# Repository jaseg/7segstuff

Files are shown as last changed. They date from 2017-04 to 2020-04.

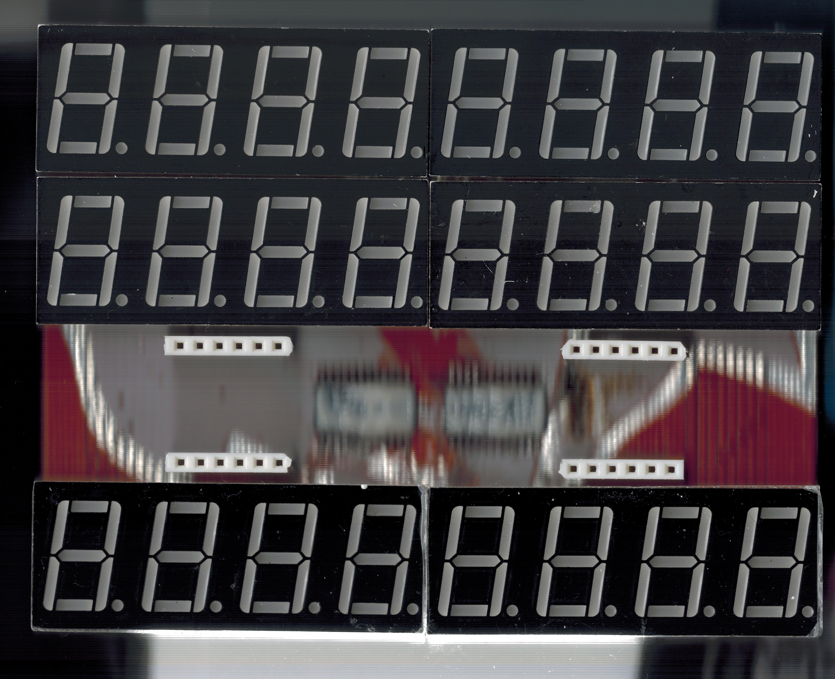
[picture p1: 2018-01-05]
fw/tools/scans/megumin_segmentmap_600dpi.jpg

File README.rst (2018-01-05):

Megumin LED display
===================

This repository contains schematics, firmware, host controller code and board
layouts for driving of hundreds of 7-segment displays. The firmware and some
basic host software may be found in the fw directory. The hardware design files
may be found in the hw directory.

This system uses a somewhat involved LED modulation technique. For details on
that have a look at the README.rst in the fw directory as well as the
well-documented code in fw/display.c.

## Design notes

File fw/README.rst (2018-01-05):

Note on the LED modulation 
==========================

To control LED brightness, this project uses a modulation technique known as
"Binary Code Modulation" (BCM) or "Bit Angle Modulation" (BAM). The base idea is
to clock out all outputs in parallel bit-by-bit, then modulate this with a
precisely timed output enable signal. In contrast to PWM this allows almost
arbitrarily high channel counts and configurable modulation resolution at low
CPU overhead and high frame rates. In this project that is needed due to the
large number of channels (32) and the medium oversampling rate (1:8).

A good article explaining BCM can be found on batsocks.co.uk_ and a nice video
explaining has been published by mikeselectricstuff_. A possible optimization
for even smoother brightness fading (probably mostly in unmultiplexed
applications) has been discussed in the forums at picbasic.co.uk_.

.. _mikeselectricstuff: https://www.youtube.com/watch?v=Sq8SxVDO5wE
.. _`picbasic.co.uk`: http://www.picbasic.co.uk/forum/showthread.php?t=7393
.. _batsocks.co.uk: http://www.batsocks.co.uk/readme/art_bcm_1.htm

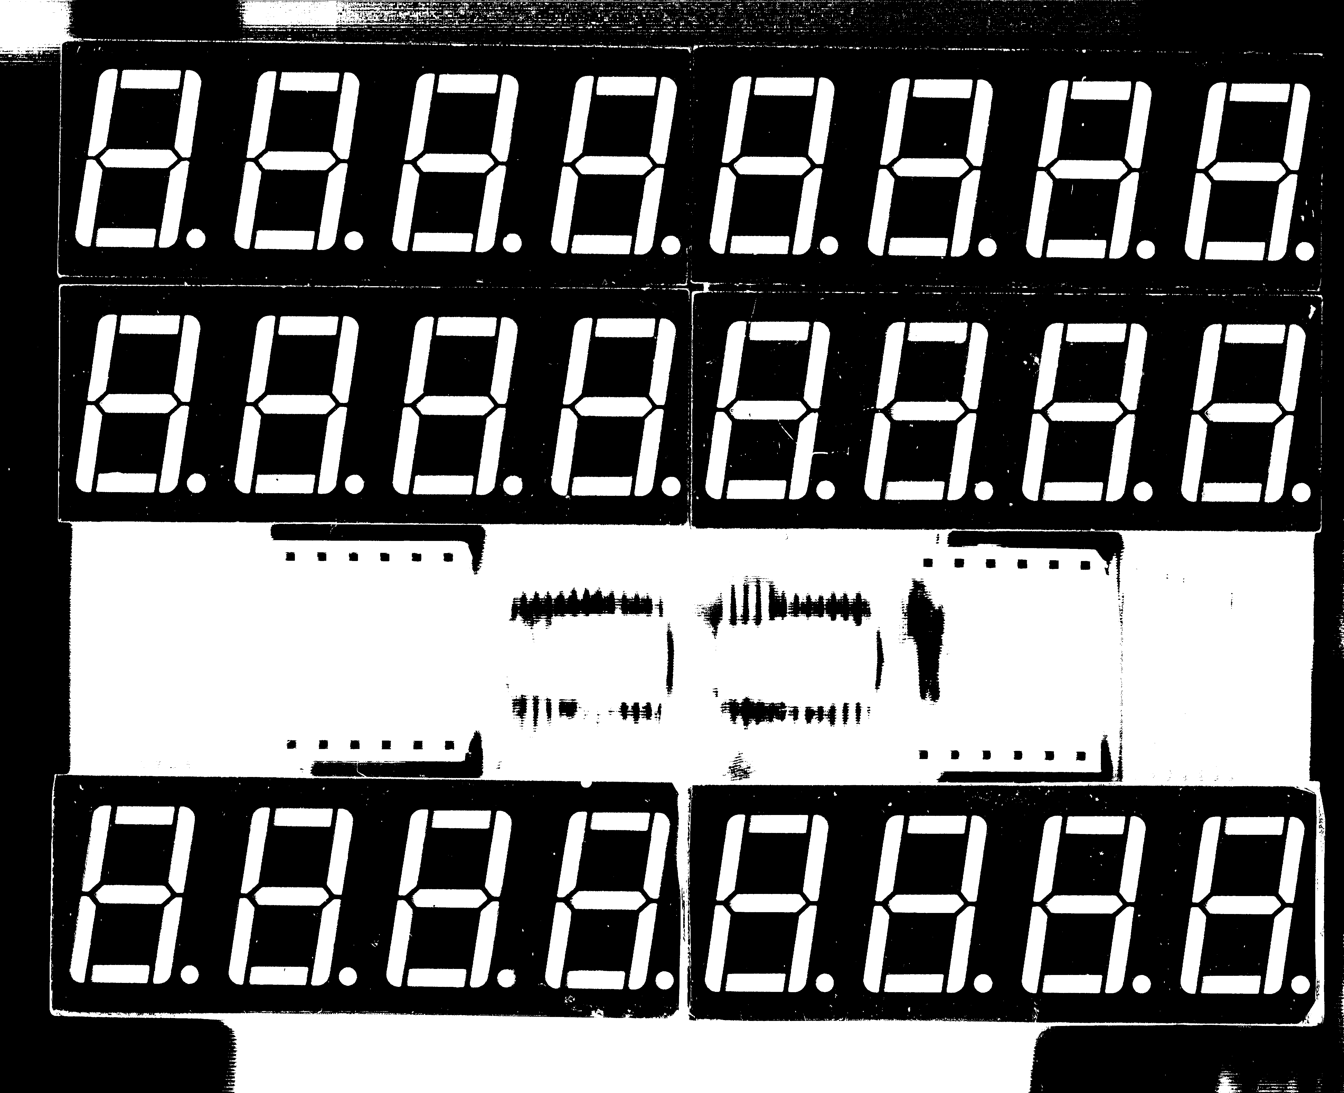
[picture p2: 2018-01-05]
fw/tools/scans/pretty2.png

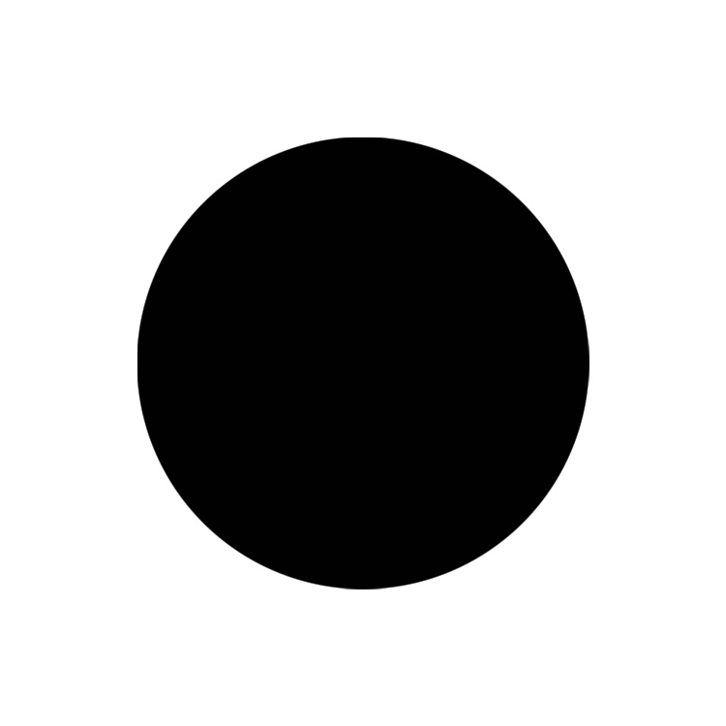
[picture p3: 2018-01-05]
fw/tools/circle.jpg

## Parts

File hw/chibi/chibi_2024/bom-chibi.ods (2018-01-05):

Chibi/Megumin
Number of devices: | Base: | 20
 | w/ cmeas: | 0
 | w/ watchdog: | 20
Description | Package | Mfg | Mfg Part No | Supplier | Reichelt PN | Qty watchdog | Qty cmeas | Qty base | MOQ | Unit | Price/ Unit | Price watchdog | Price cmeas | Price base | Price total | MOQ match | Price total MOQ | Excl | TempSum | MOQ delta cost | MOQ delta qty | URL
MLC X7R 100n | 0603 | Yageo | CC0603KRX7R7BB104 | Reichelt | X7R-G0603 100N | 1 | 1 | 8 | 10 | Pcs | 0.04 € | 0.04 € | 0.04 € | 0.32 € | 7.20 € | 180 | 7.20 € |  | 7.20 € | 0.00 € | 0 | https://www.reichelt.de/Vielschicht-SMD-G0603/X7R-G0603-100N/3/index.html?ACTION=3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
Electrolytic cap 1000u/10V | D10 L20 R5 | NCC | ELXZ160ETD102MJ20S | Reichelt | RAD LXZ 16/1K0 |  |  | 1 | 1 | Pcs | 0.24 € | 0.00 € | 0.00 € | 0.24 € | 4.80 € | 20 | 4.80 € |  | 4.80 € | 0.00 € | 0 | https://www.reichelt.de/Elkos-radial-105-C-5000-10000h/RAD-LXZ-16-1K0/3/index.html?ACTION=3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
Electrolytic cap 47u/6V | SMD 5x5.8 | Panasonic | EEEFK1C470UR | Reichelt | VF 47/16 K-C |  |  | 1 | 1 | Pcs | 0.12 € | 0.00 € | 0.00 € | 0.12 € | 2.40 € | 20 | 2.40 € |  | 2.40 € | 0.00 € | 0 | https://www.reichelt.de/Elkos-SMD-Low-ESR-105-C/VF-47-16-K-C/3/index.html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
MLC X7R 10n | 0603 | RND | RND1500603B224K100 | Reichelt | X7R-G0603 10N |  |  | 1 | 10 | Pcs | 0.04 € | 0.00 € | 0.00 € | 0.04 € | 0.80 € | 20 | 0.80 € |  | 0.80 € | 0.00 € | 0 | https://www.reichelt.de/Vielschicht-SMD-G0603/X7R-G0603-10N/3/index.html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
MLC X7R 220n | 0603 | Yageo | CC0603KRX7R9BB103 | Reichelt | X7R 0603 CC 220N |  | 2 |  | 10 | Pcs | 0.04 € | 0.00 € | 0.08 € | 0.00 € | 0.00 € | 0 | 0.00 € |  | 0.00 € | 0.00 € | 0 | https://www.reichelt.de/Vielschicht-SMD-G0603/X7R-0603-CC-220N/3/index.html?ACTION=3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
MLC NP0 22p | 0603 | Yageo | CC0603JRNPO9BN220 | Reichelt | NPO-G0603 22P |  |  | 2 | 10 | Pcs | 0.04 € | 0.00 € | 0.00 € | 0.08 € | 1.60 € | 40 | 1.60 € |  | 1.60 € | 0.00 € | 0 | https://www.reichelt.de/Vielschicht-SMD-G0603/NPO-G0603-22P/3/index.html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
Zener 6.4V 1.3W | THT | Generic |  | Reichelt | ZD 6,8 |  |  | 1 | 1 | Pcs | 0.06 € | 0.00 € | 0.00 € | 0.06 € | 1.20 € | 20 | 1.20 € |  | 1.20 € | 0.00 € | 0 | https://www.reichelt.de/Z-Dioden-1-3W/ZD-6-8/3/index.html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
LED red | 0603 | Everlight | 19-213/R6C-AQ1R2B/3T | Reichelt | LED EL 0603 RT |  |  | 1 | 10 | Pcs | 0.08 € | 0.00 € | 0.00 € | 0.08 € | 1.60 € | 20 | 1.60 € |  | 1.60 € | 0.00 € | 0 | https://www.reichelt.de/SMD-LEDs-Standard/LED-EL-0603-RT/3/index.html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
LED yellow | 0603 | Everlight | 19-213/Y2C-CQ2R2L/3T | Reichelt | LED EL 0603 GE |  |  | 1 | 10 | Pcs | 0.06 € | 0.00 € | 0.00 € | 0.06 € | 1.20 € | 20 | 1.20 € |  | 1.20 € | 0.00 € | 0 | https://www.reichelt.de/SMD-LEDs-Standard/LED-EL-0603-GE/3/index.html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
LED green | 0603 | Everlight | LED EL 0603 GR1 | Reichelt | LED EL 0603 GR1 |  |  | 1 | 10 | Pcs | 0.10 € | 0.00 € | 0.00 € | 0.10 € | 2.00 € | 20 | 2.00 € |  | 2.00 € | 0.00 € | 0 | https://www.reichelt.de/SMD-LEDs-Standard/LED-EL-0603-GR1/3/index.html?ACTION=3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
Glass Fuse 5x20mm MT 2.5A | other | Generic |  | Reichelt | MTR. 2,5A |  |  | 1 | 10 | Pcs | 0.08 € | 0.00 € | 0.00 € | 0.08 € | 1.58 € | 20 | 1.58 € |  | 1.58 € | 0.00 € | 0 | https://www.reichelt.de/?ACTION=3;ARTICLE=13246;SEARCH=MT%202,5A
Fuse holder 5x20mm (single) | other | Generic |  | Reichelt | PL 120000 |  |  | 2 | 1 | Pcs | 0.06 € | 0.00 € | 0.00 € | 0.12 € | 2.40 € | 40 | 2.40 € |  | 2.40 € | 0.00 € | 0 | https://www.reichelt.de/Sicherungshalter/PL-120000/3/index.html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
Spade connector 6.35mm | THT | Generic |  | Reichelt | FS-P 6,35 |  |  | 0 | 10 | Pcs | 0.05 € | 0.00 € | 0.00 € | 0.00 € | 0.00 € | 0 | 0.00 € |  | 0.00 € | 0.00 € | 0 | https://www.reichelt.de/Flachstecker/FS-P-6-35/3/index.html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
Female header 1x4 100mil | other | Generic |  | Reichelt | SL 1X36G 2,54 |  |  | 1 | 9 | Pcs | 0.02 € | 0.00 € | 0.00 € | 0.02 € | 0.38 € | 27 | 0.51 € |  | 0.51 € | 0.13 € | 7 | https://www.reichelt.de/Stiftleisten/SL-1X36G-2-54/3/index.html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
Shrouded male header 2x5 100mil | other | Generic |  | Reichelt | WSL 10G |  |  | 1 | 1 | Pcs | 0.09 € | 0.00 € | 0.00 € | 0.09 € | 1.80 € | 20 | 1.80 € |  | 1.80 € | 0.00 € | 0 | https://www.reichelt.de/Pfosten-Wannenstecker/WSL-10G/3/index.html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
PNP signal transistor | SOT-23 | Generic |  | Reichelt | BC 857C SMD | 1 |  |  | 10 | Pcs | 0.04 € | 0.04 € | 0.00 € | 0.00 € | 0.80 € | 20 | 0.80 € |  | 0.80 € | 0.00 € | 0 | https://www.reichelt.de/BC-Transistoren/BC-857C-SMD/3/index.html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
NPN signal transistor | SOT-23 | Generic |  | Reichelt | BC 847C SMD |  |  | 2 | 10 | Pcs | 0.04 € | 0.00 € | 0.00 € | 0.08 € | 1.60 € | 40 | 1.60 € |  | 1.60 € | 0.00 € | 0 | https://www.reichelt.de/BC-Transistoren/BC-847C-SMD/3/index.html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
Metal film resistor 10k 1% | 0603 | Yageo | RC0603FR-0710KL | Reichelt | SMD-0603 10K | 2 | 4 | 2 | 10 | Pcs | 0.02 € | 0.03 € | 0.06 € | 0.03 € | 1.20 € | 80 | 1.20 € |  | 1.20 € | 0.00 € | 0 | https://www.reichelt.de/SMD-0603-von-1-bis-910-kOhm/SMD-0603-10K/3/index.html?ACTION=3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
Metal film resistor 47k 1% | 0603 | Yageo | RC0603FR-0747KL | Reichelt | SMD-0603 47K | 3 | 4 |  | 10 | Pcs | 0.02 € | 0.05 € | 0.06 € | 0.00 € | 0.90 € | 60 | 0.90 € |  | 0.90 € | 0.00 € | 0 | https://www.reichelt.de/SMD-0603-von-1-bis-910-kOhm/SMD-0603-47K/3/index.html?ACTION=3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
Metal film resistor 100k 1% | 0603 | Yageo | RC0603FR-07100KL | Reichelt | SMD-0603 100K | 2 |  | 4 | 10 | Pcs | 0.02 € | 0.03 € | 0.00 € | 0.06 € | 1.80 € | 120 | 1.80 € |  | 1.80 € | 0.00 € | 0 | https://www.reichelt.de/SMD-0603-von-1-bis-910-kOhm/SMD-0603-100K/3/index.html?ACTION=3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
Metal film resistor 4k7 1% | 0603 | Yageo | RC0603FR-074K7L | Reichelt | SMD-0603 4,7K |  | 3 | 2 | 10 | Pcs | 0.02 € | 0.00 € | 0.05 € | 0.03 € | 0.60 € | 40 | 0.60 € |  | 0.60 € | 0.00 € | 0 | https://www.reichelt.de/SMD-0603-von-1-bis-910-kOhm/SMD-0603-4-7K/3/index.html?ACTION=3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
Metal film resistor 1k 1% | 0603 | Yageo | RC0603FR-071KL | Reichelt | SMD-0603 1,0K |  | 1 |  | 10 | Pcs | 0.02 € | 0.00 € | 0.02 € | 0.00 € | 0.00 € | 0 | 0.00 € |  | 0.00 € | 0.00 € | 0 | https://www.reichelt.de/SMD-0603-von-1-bis-910-kOhm/SMD-0603-1-0K/3/index.html?ACTION=3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
Metal film resistor 470k 1% | 0603 | Yageo | RC0603FR-07470KL | Reichelt | SMD-0603 470K |  |  | 2 | 10 | Pcs | 0.02 € | 0.00 € | 0.00 € | 0.03 € | 0.60 € | 40 | 0.60 € |  | 0.60 € | 0.00 € | 0 | https://www.reichelt.de/SMD-0603-von-1-bis-910-kOhm/SMD-0603-470K/3/index.html?ACTION=3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
Metal film resistor 100 1% | 0603 | Yageo | RC0603FR-07100RL | Reichelt | SMD-0603 100 |  |  | 2 | 10 | Pcs | 0.02 € | 0.00 € | 0.00 € | 0.03 € | 0.60 € | 40 | 0.60 € |  | 0.60 € | 0.00 € | 0 | https://www.reichelt.de/SMD-0603-von-0-bis-910-Ohm/SMD-0603-100/3/index.html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
Metal film resistor 140 1% | 0603 | Yageo | RC0603FR-07150RL | Reichelt | SMD-0603 150 |  |  | 1 | 10 | Pcs | 0.02 € | 0.00 € | 0.00 € | 0.02 € | 0.30 € | 20 | 0.30 € |  | 0.30 € | 0.00 € | 0 | https://www.reichelt.de/SMD-0603-von-0-bis-910-Ohm/SMD-0603-150/3/index.html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
DAC resistor 1 | 0603 | Yageo |  | Reichelt |  |  |  | 2 | 10 | Pcs | 0.02 € | 0.00 € | 0.00 € | 0.03 € | 0.60 € | 40 | 0.60 € |  | 0.60 € | 0.00 € | 0
DAC resistor 2 | 0603 | Yageo |  | Reichelt |  |  |  | 2 | 10 | Pcs | 0.02 € | 0.00 € | 0.00 € | 0.03 € | 0.60 € | 40 | 0.60 € |  | 0.60 € | 0.00 € | 0
Linear voltage reg 3.3V | SOT-223 | Generic | LD1117-3.3 | Reichelt | TS 1117 BCW33 |  |  | 0 | 1 | Pcs | 0.32 € | 0.00 € | 0.00 € | 0.00 € | 0.00 € | 0 | 0.00 € |  | 0.00 € | 0.00 € | 0 | https://www.reichelt.de/ICs-TLC-TSA-/TS-1117-BCW33/3/index.html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
Generic dual op-amp | SO-8 | Generic | LM358 | Reichelt | LM 358 SMD |  | 1 |  | 1 | Pcs | 0.15 € | 0.00 € | 0.15 € | 0.00 € | 0.00 € | 0 | 0.00 € |  | 0.00 € | 0.00 € | 0 | https://www.reichelt.de/ICs-LM-10-LM-999/LM-358-SMD/3/index.html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
Generic dual comparator | SO-8 | Generic | LM393 | Reichelt | LM 393 D SMD | 1 |  |  | 1 | Pcs | 0.15 € | 0.15 € | 0.00 € | 0.00 € | 3.00 € | 20 | 3.00 € |  | 3.00 € | 0.00 € | 0 | https://www.reichelt.de/ICs-LM-10-LM-999/LM-393-D-SMD/3/index.html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
Crystal 8MHz | HC49 SMD | Generic |  | Reichelt | 8,0000-HC49-SMD |  |  | 1 | 1 | Pcs | 0.25 € | 0.00 € | 0.00 € | 0.25 € | 5.00 € | 20 | 5.00 € |  | 5.00 € | 0.00 € | 0 | https://www.reichelt.de/Quarze/8-0000-HC49-SMD/3/index.html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
Quad bus driver (level shifter) | SO-14 | Generic | 74HCT125 | Segor |  |  |  | 1 | 10 | Pcs | 0.20 € | 0.00 € | 0.00 € | 0.20 € | 4.00 € | 20 | 4.00 € |  | 4.00 € | 0.00 € | 0 | http://www.segor.de/#Q=74HCT125-SMD&M=1
Latched shift register | SO-16 | Generic | 74HC595/74HCT595 | Aliexpress | SMD HC 595 |  |  | 2 | 1 | Pcs | 0.20 € | 0.00 € | 0.00 € | 0.40 € | 8.00 € | 40 | 8.00 € |  | 8.00 € | 0.00 € | 0 | https://www.reichelt.de/ICs-74HC-SMD/SMD-HC-595/3/index.html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
Signal diode | MiniMELF |  | 1N4148 | Aliexpress | 1N 4148 SMD | 3 |  |  | 10 | Pcs | 0.04 € | 0.12 € | 0.00 € | 0.00 € | 2.40 € | 60 | 2.40 € |  | 2.40 € | 0.00 € | 0 | https://www.reichelt.de/1N-UF-AA-Dioden/1N-4148-SMD/3/index.html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
RS-485 transceiver | SO-8 | Generic | MAX485 | Aliexpress | SP 485 CNL |  |  | 1 | 1 | Pcs | 0.04 € | 0.00 € | 0.00 € | 0.04 € | 0.80 € | 20 | 0.80 € |  | 0.80 € | 0.00 € | 0 | https://www.reichelt.de/ICs-NE-STV-/SP-485-CNL/3/index.html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
Tactile button | FSMSM |  |  | Aliexpress |  |  |  | 2 | 10 | Pcs | 0.01 € | 0.00 € | 0.00 € | 0.02 € | 0.40 € | 40 | 0.40 € |  | 0.40 € | 0.00 € | 0
LED driver | SSOP24-1.0 | Generic | MBI5026 | Aliexpress |  |  |  | 2 | 10 | Pcs | 0.20 € | 0.00 € | 0.00 € | 0.40 € | 8.00 € | 40 | 8.00 € |  | 8.00 € | 0.00 € | 0
ARM microcontroller | TSSOP-20 | ST | STM32F030F4P6 | Aliexpress | STM 32F030F4P6 |  |  | 1 | 25 | Pcs | 0.50 € | 0.00 € | 0.00 € | 0.50 € | 10.00 € | 25 | 12.50 € |  | 12.50 € | 2.50 € | 5 | https://www.reichelt.de/ICs-NE-STV-/STM-32F030F4P6/3/index.html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
P-Ch MOSFET 30V/5A | SOT-23 | AO Semi | AO3415A | Aliexpress |  |  |  | 8 | 5 | Pcs | 0.05 € | 0.00 € | 0.00 € | 0.40 € | 8.00 € | 160 | 8.00 € |  | 8.00 € | 0.00 € | 0
Metal film resistor 0R1 1% | 2512 |  |  | Aliexpress |  |  | 1 |  | 50 | Pcs |  | 0.00 € | 0.00 € | 0.00 € | 0.00 € | 0 | 0.00 € | 1 | 0.00 € | 0.00 € | 0
4dig 7seg CC display red | other |  |  | Aliexpress |  |  |  | 8 | 5 | Pcs | 0.30 € | 0.00 € | 0.00 € | 2.40 € | 48.00 € | 160 | 48.00 € |  | 48.00 € | 0.00 € | 0
M3 pillar | other |  |  | Aliexpress |  |  |  | 4 | 200 | Pcs | 0.05 € | 0.00 € | 0.00 € | 0.20 € | 4.00 € | 200 | 10.00 € |  | 10.00 € | 6.00 € | 120
PCB |  |  |  |  |  |  |  | 1 | 50 | Pcs | 2.00 € | 0.00 € | 0.00 € | 2.00 € | 40.00 € | 50 | 100.00 € |  | 100.00 € | 60.00 € | 30
 |  |  |  |  |  |  |  |  |  |  | Total | 0.46 € | 0.45 € | 8.55 € | 180.16 € |  |  | Total | 248.79 € | 68.63 €
Notes:
LED driver current set DAC resistors remain to be fixed
Check NPN/PNP BJT pinouts

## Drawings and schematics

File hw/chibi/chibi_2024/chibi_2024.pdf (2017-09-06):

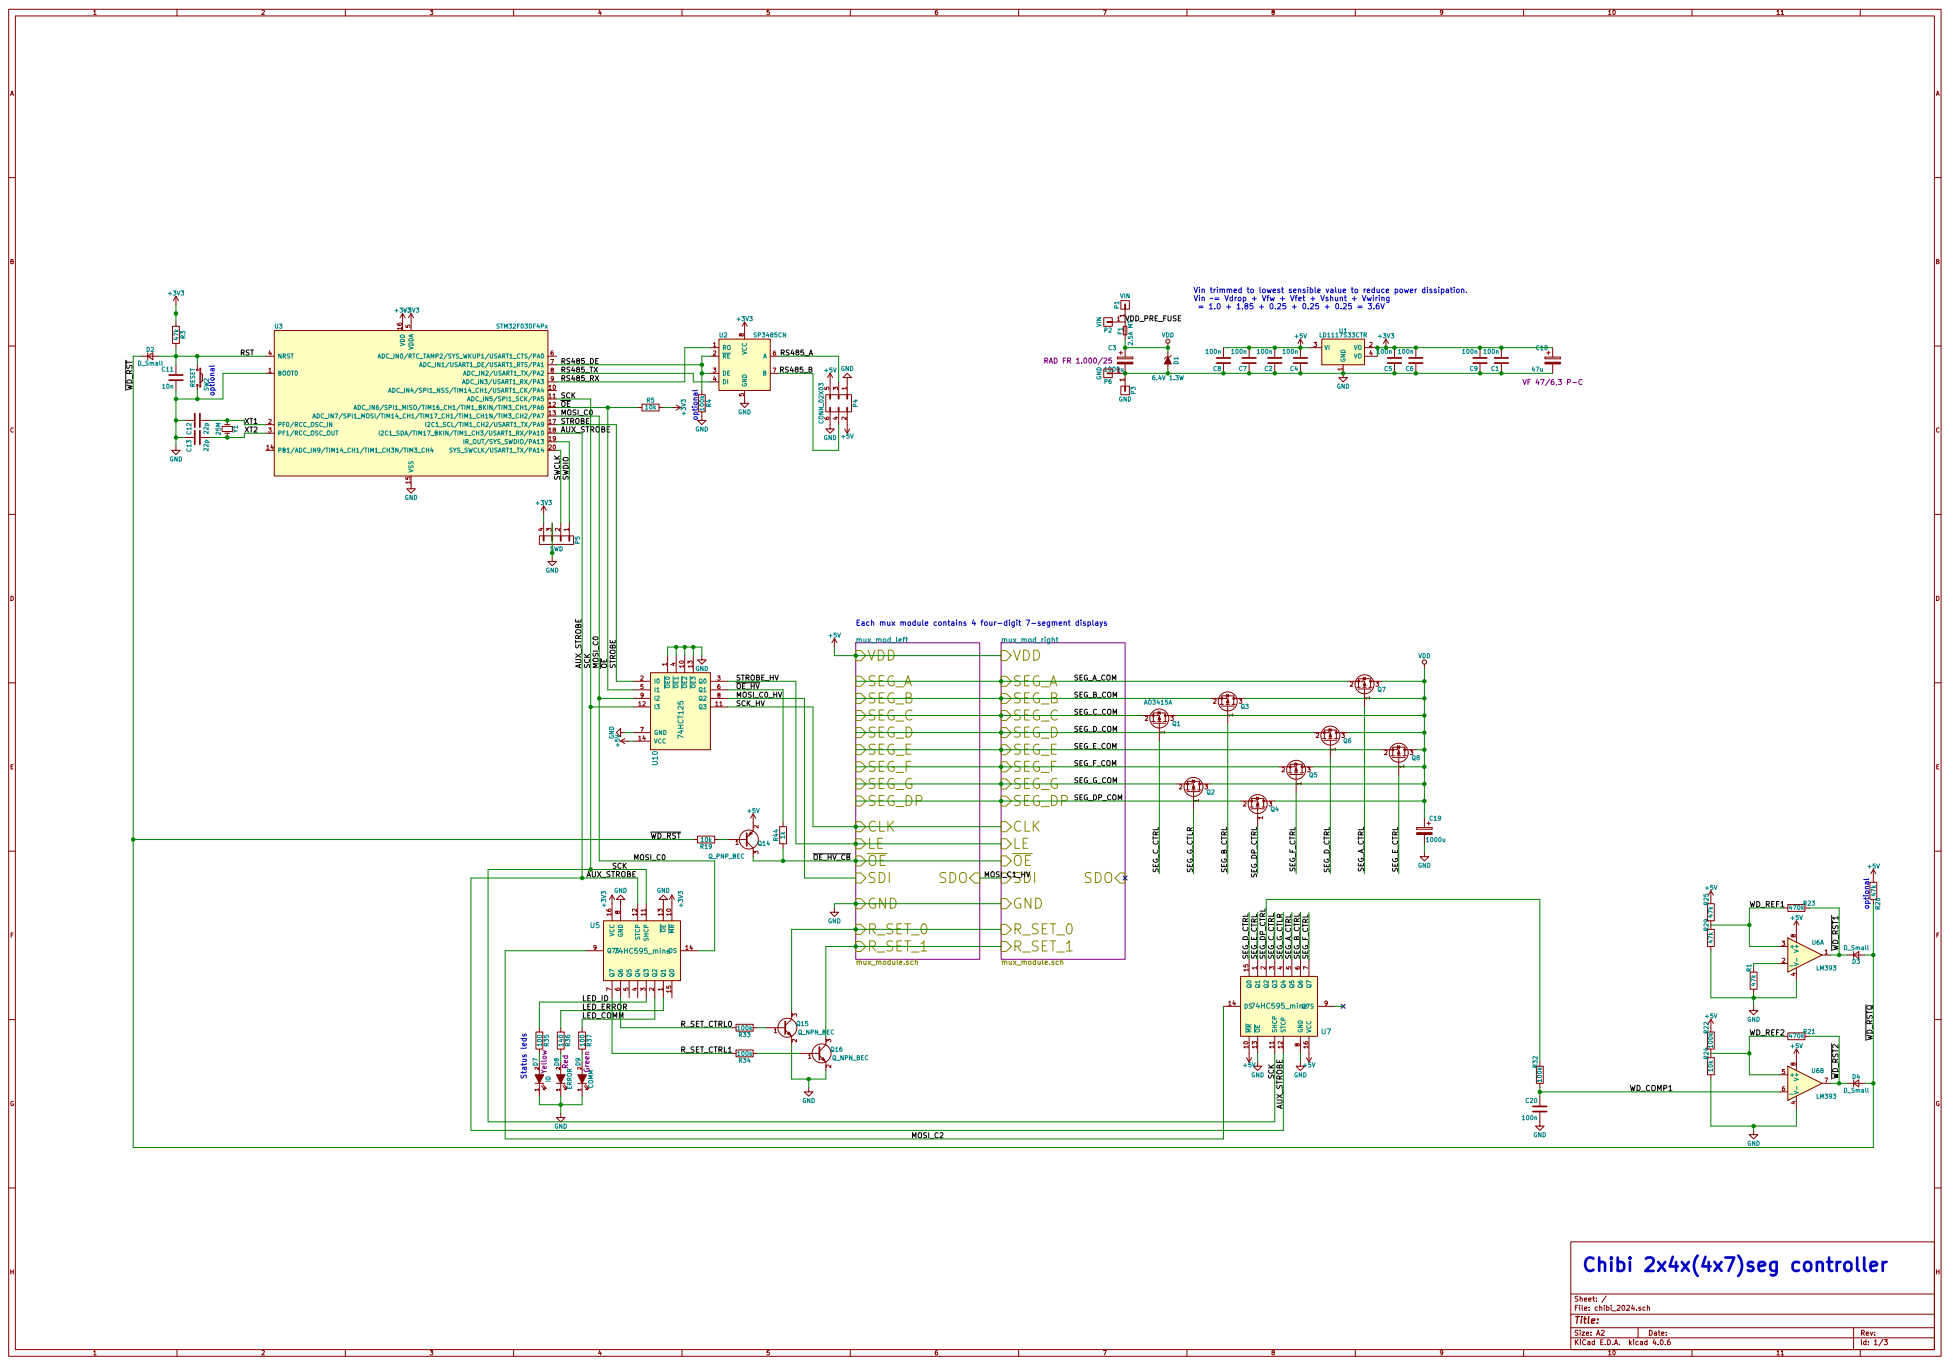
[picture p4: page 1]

Vin trimmed to lowest sensible value to reduce power dissipation.
Vin = Vdrop + Vfw + Vfet + Vshunt + Vwiring

RS485_TX
RS485_RX

1 P3 GND Chibi 2x4x(4x7)seg controller

SEG_D
SEG_E
SEG_F
SEG_G

8 Q7S 9 MR 10 SHCP 11 STCP 12 OE 13 DS 14 Q0 15 VCC 16 U5

LED_ERROR
LED_COMM

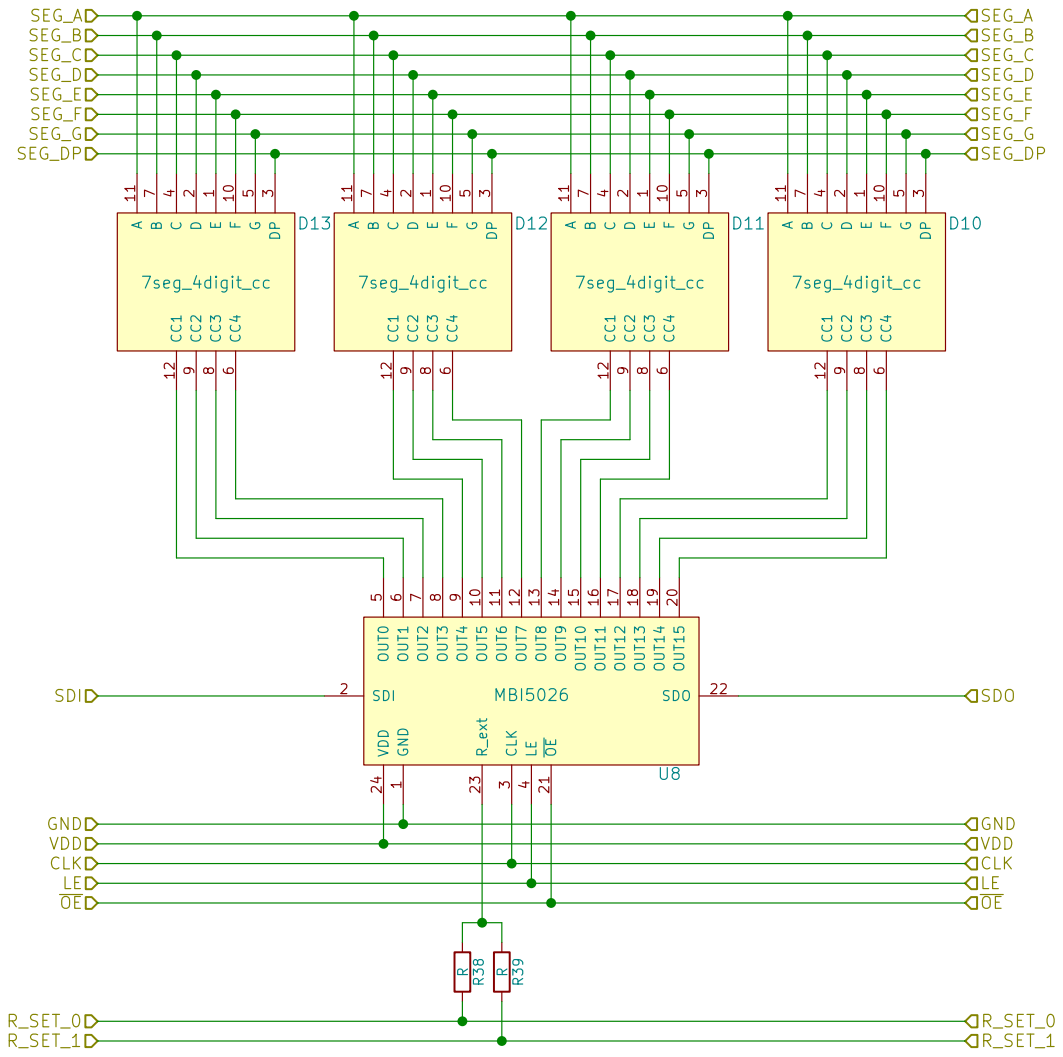
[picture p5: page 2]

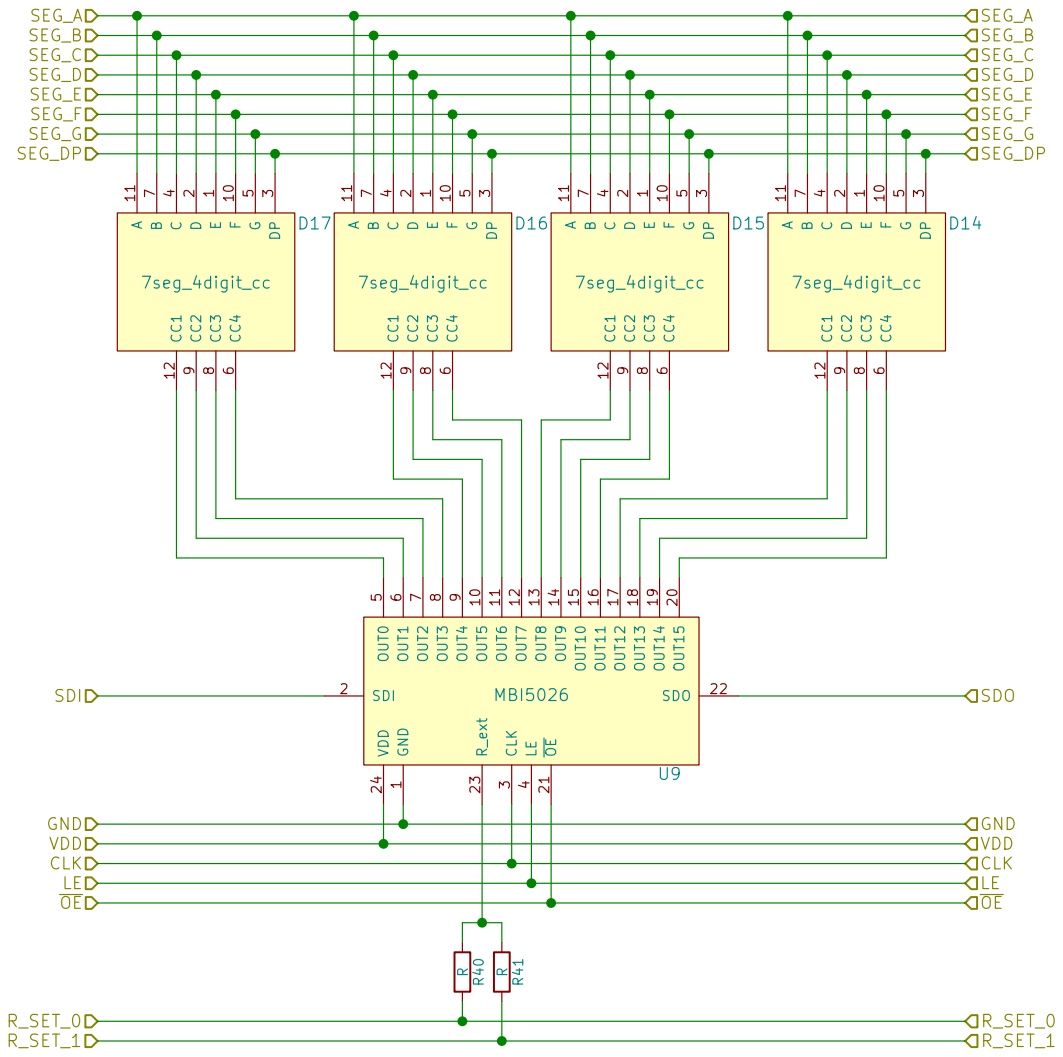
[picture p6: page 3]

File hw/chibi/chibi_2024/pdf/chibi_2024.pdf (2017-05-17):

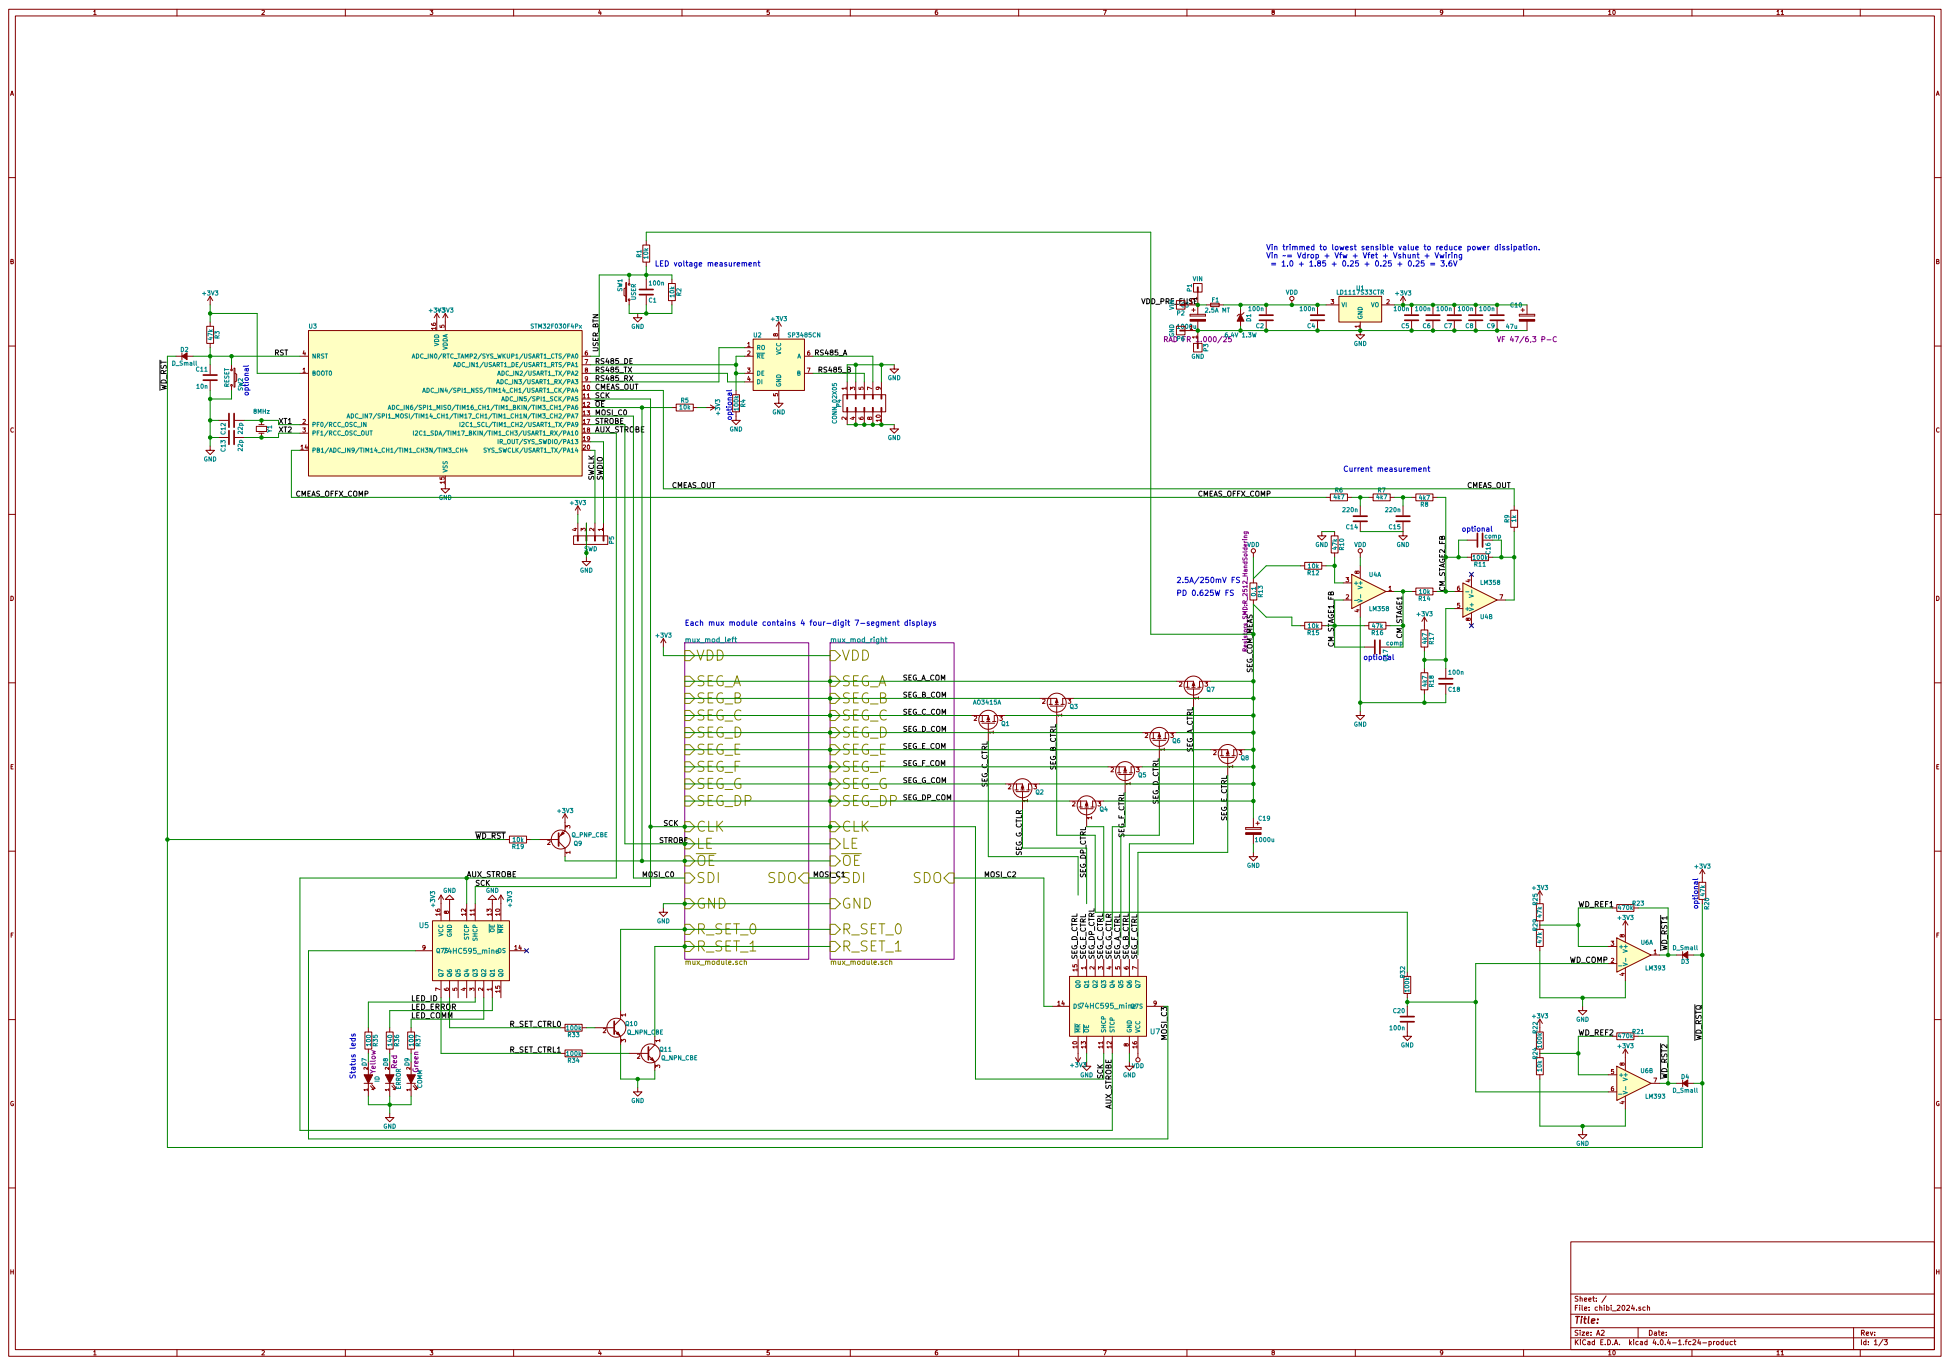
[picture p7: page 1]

Vin trimmed to lowest sensible value to reduce power dissipation.
Vin = Vdrop + Vfw + Vfet + Vshunt + Vwiring

1 P3 GND Chibi 2x4x(4x7)seg controller

RS485_TX
RS485_RX

MOSI_C0
STROBE

Each mux module contains 4 four-digit 7-segment displays
VDD
SEG_A

SEG_B
SEG_C | 2 | 3Q1 AO3415A
SEG_D
SEG_E
SEG_F
SEG_G

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

8 Q7S 9 MR 10 SHCP 11 STCP 12 OE 13 DS 14 Q0 15 VCC 16 U7

LED_ERROR
LED_COMM



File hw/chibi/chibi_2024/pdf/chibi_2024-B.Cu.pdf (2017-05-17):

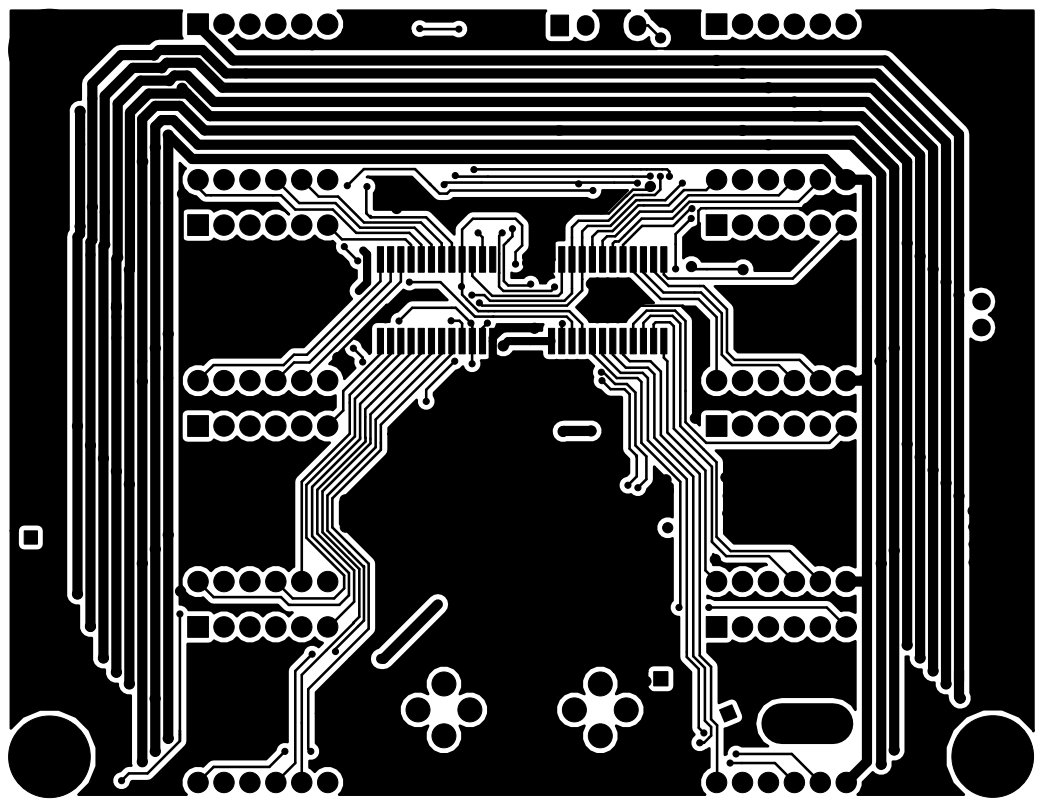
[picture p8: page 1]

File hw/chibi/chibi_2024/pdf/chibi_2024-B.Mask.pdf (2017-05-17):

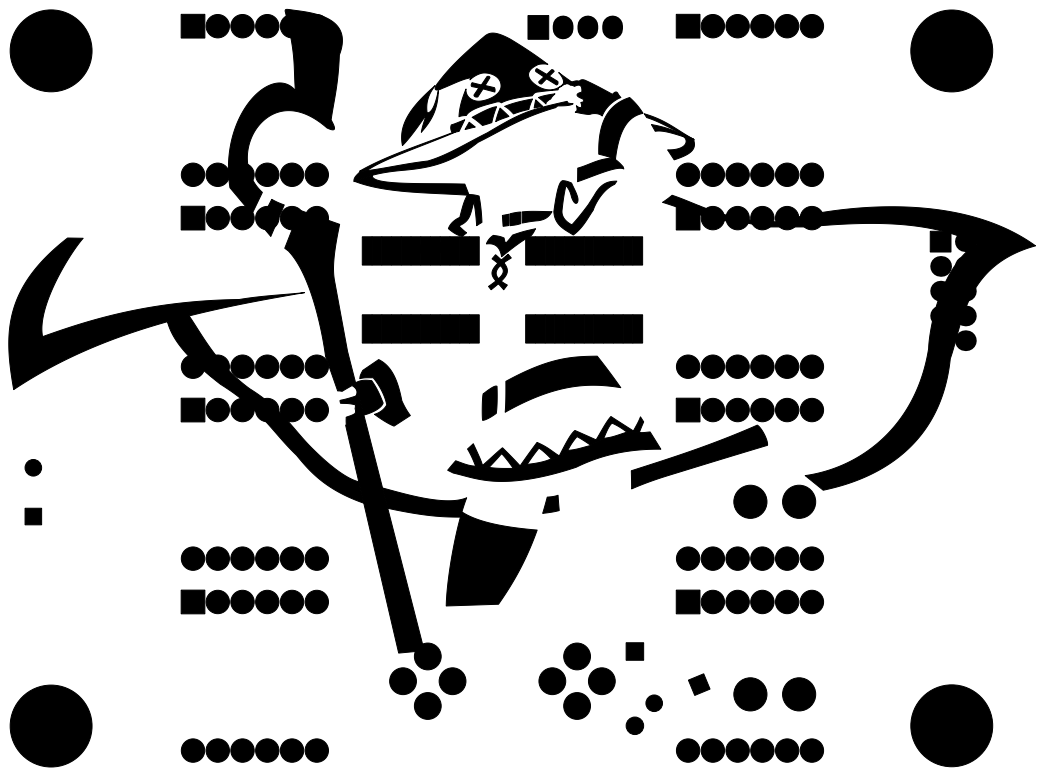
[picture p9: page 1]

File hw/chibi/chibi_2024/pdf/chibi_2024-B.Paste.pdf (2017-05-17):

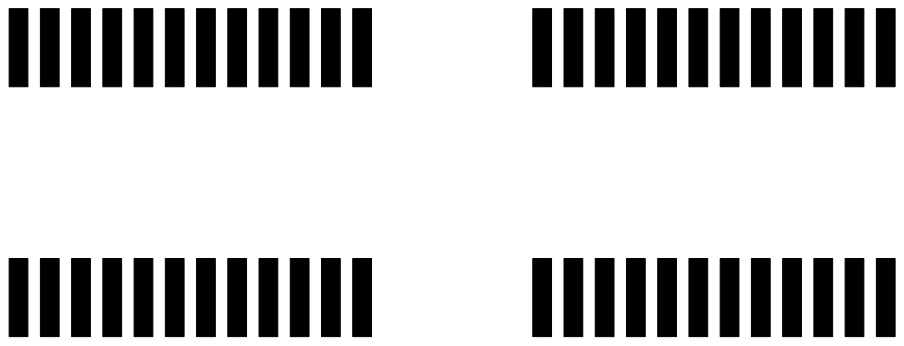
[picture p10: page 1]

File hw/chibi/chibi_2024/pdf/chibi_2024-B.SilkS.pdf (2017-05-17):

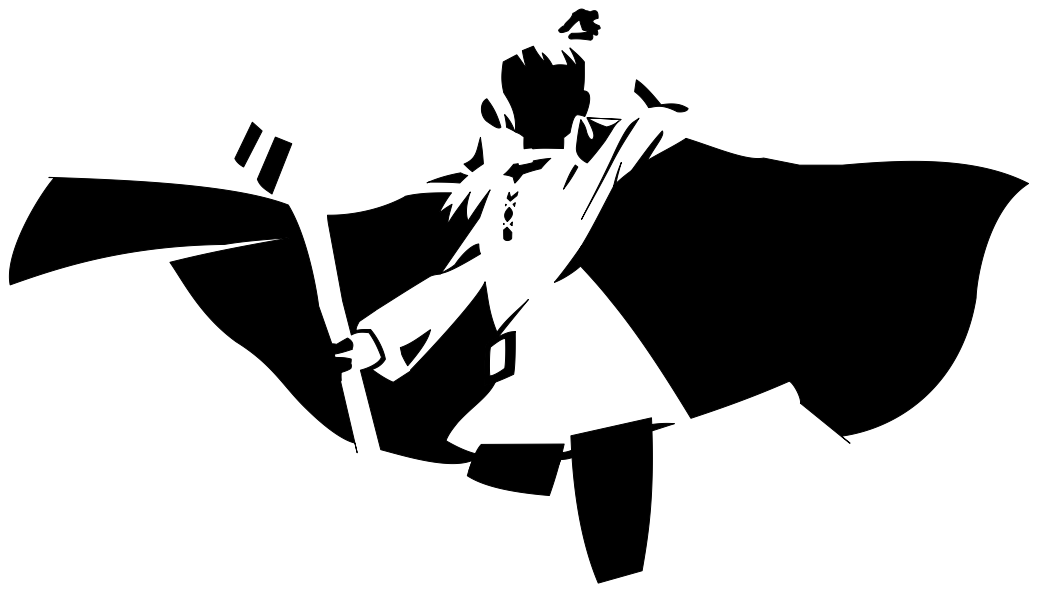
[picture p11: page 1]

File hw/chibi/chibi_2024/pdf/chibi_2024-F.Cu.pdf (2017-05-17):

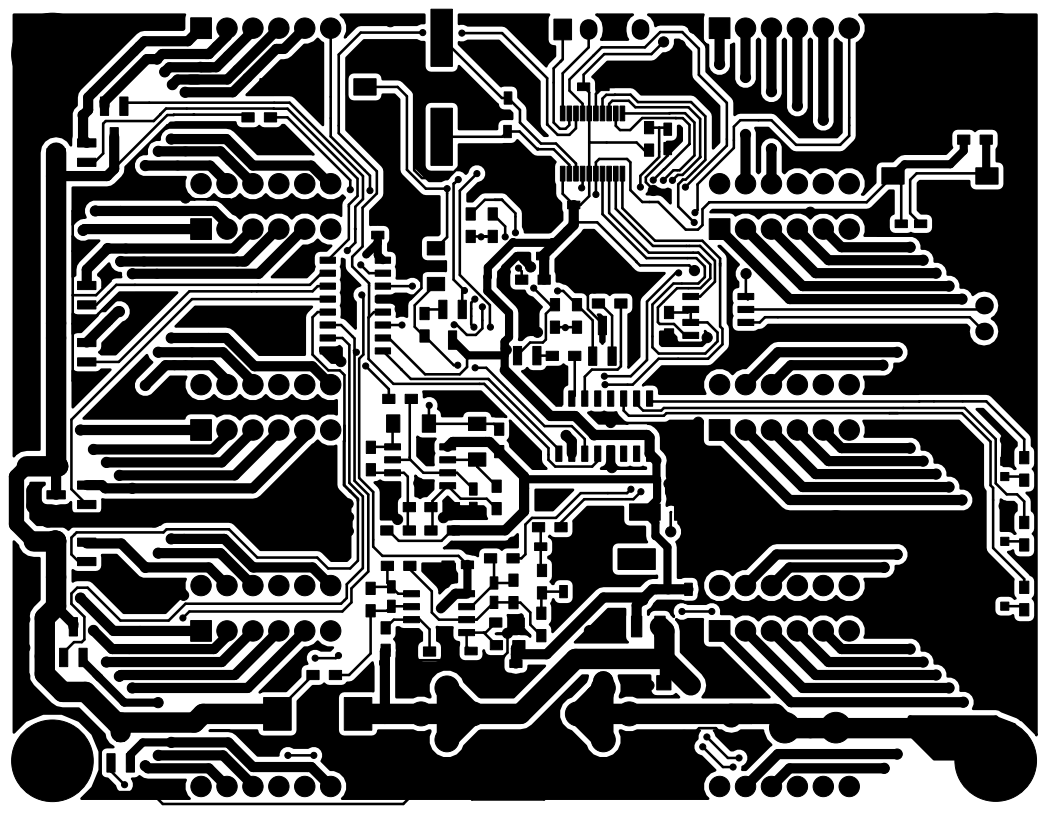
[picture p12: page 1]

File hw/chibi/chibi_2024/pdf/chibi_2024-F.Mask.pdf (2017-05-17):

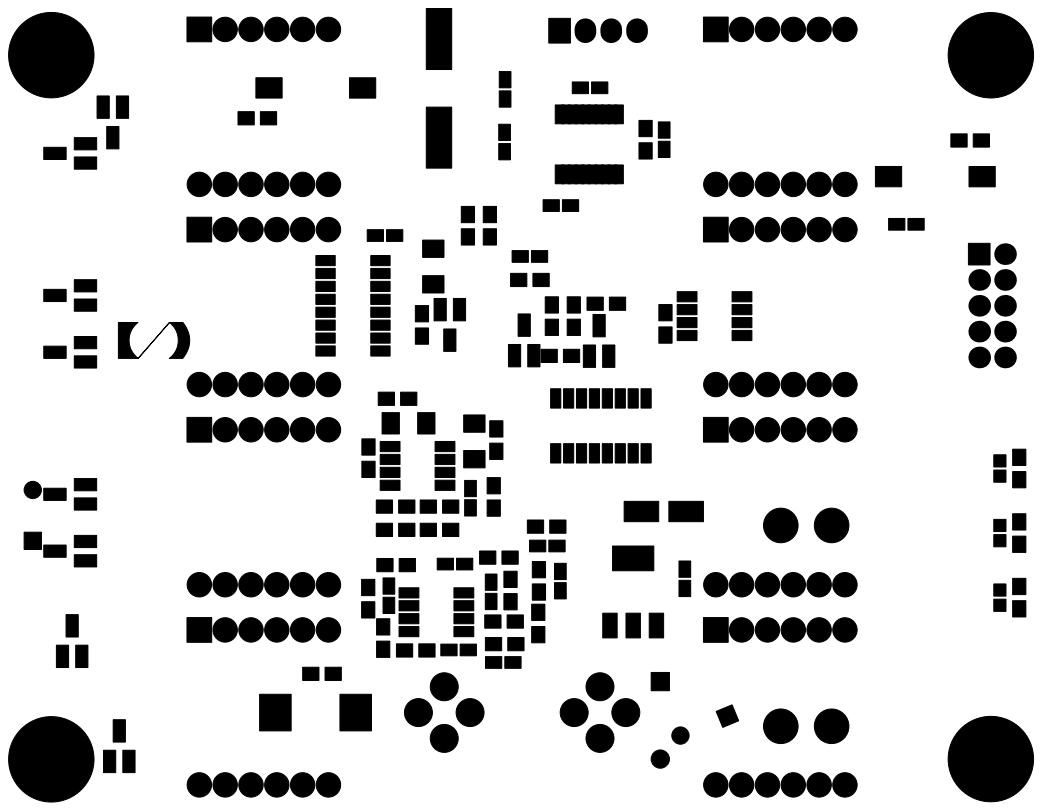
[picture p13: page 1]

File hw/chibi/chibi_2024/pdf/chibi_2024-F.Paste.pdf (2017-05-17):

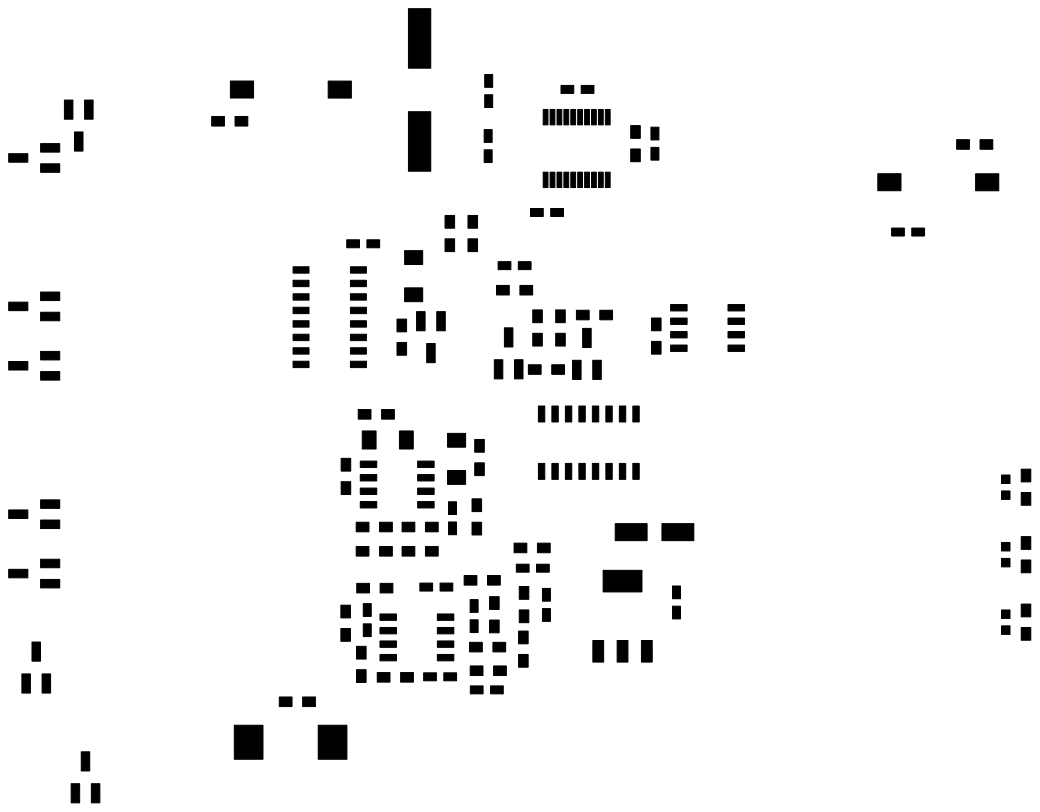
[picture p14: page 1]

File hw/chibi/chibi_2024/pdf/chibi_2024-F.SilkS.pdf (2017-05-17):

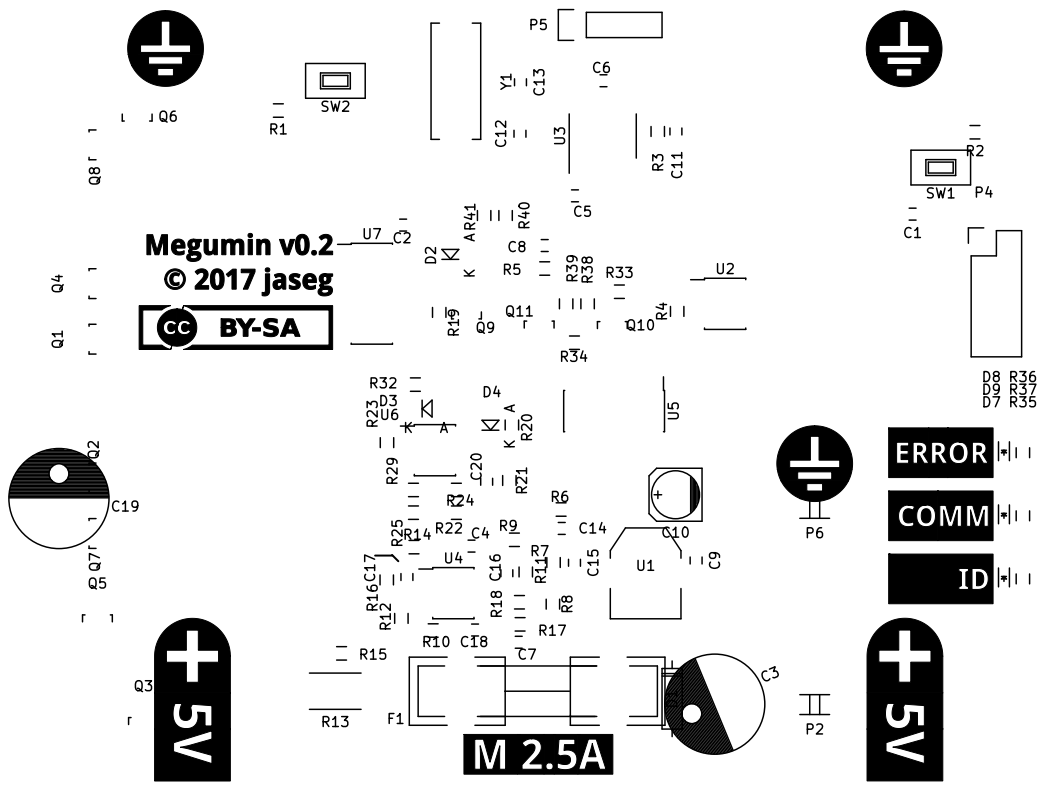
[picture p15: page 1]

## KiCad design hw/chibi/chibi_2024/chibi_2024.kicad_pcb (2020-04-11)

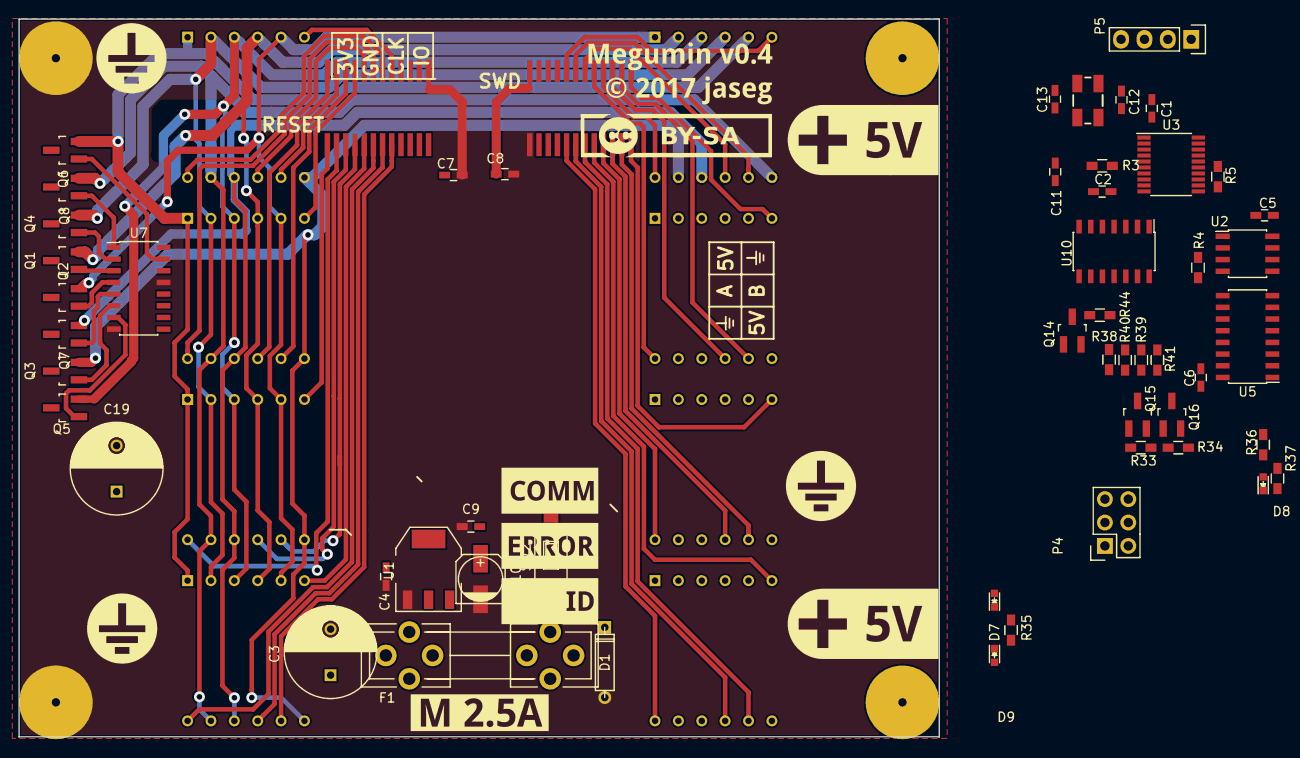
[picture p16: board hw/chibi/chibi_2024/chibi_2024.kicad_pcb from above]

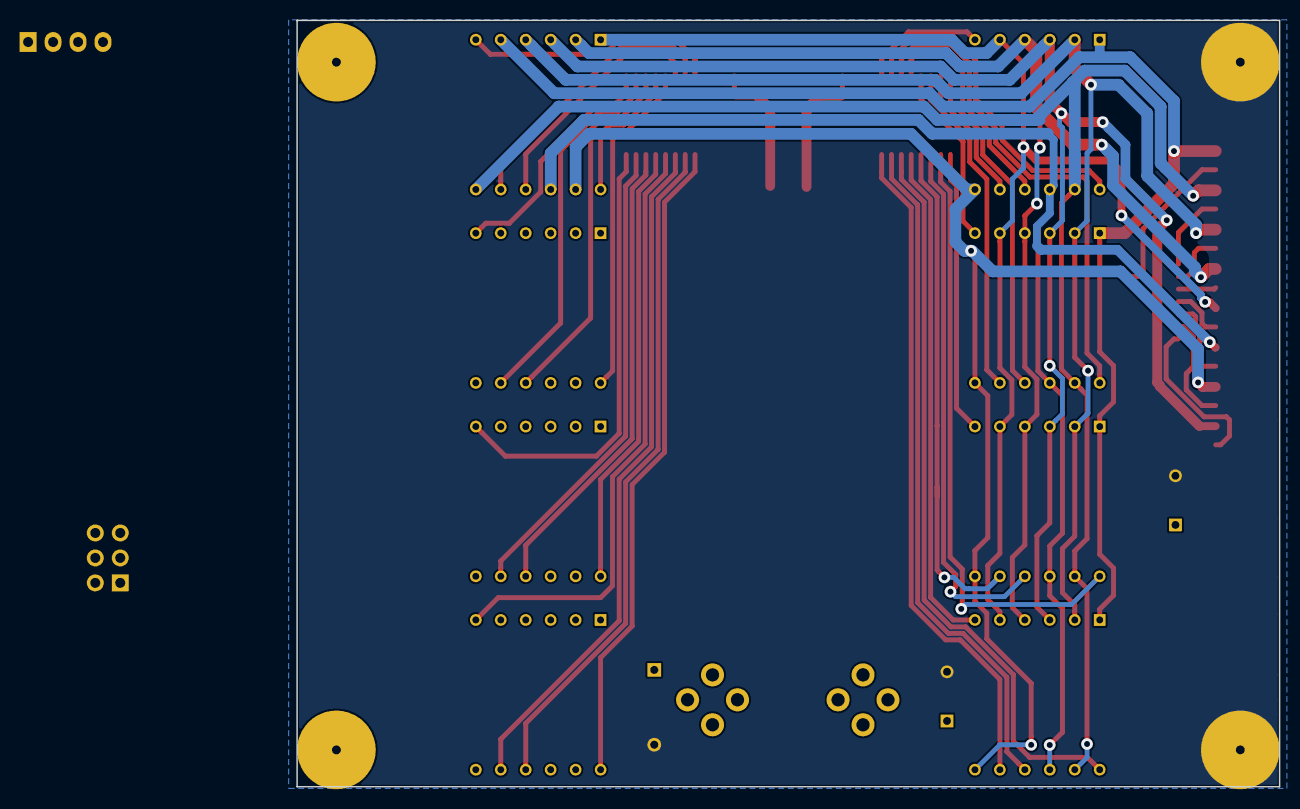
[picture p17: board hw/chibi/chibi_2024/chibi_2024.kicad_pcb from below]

Board: 2 copper layers, 100.0 x 78.0 mm, 77 parts (8 on the bottom side), 89 nets.

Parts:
C1, C2, C4, C5, C6, C7, C8, C9: 100n; C_0603_HandSoldering
C3, C19: 1000u; C_Radial_D10_L20_P5
C10: 47u; c_elec_5x5.8
C11: 10n; C_0603_HandSoldering
C12, C13: 22p; C_0603_HandSoldering
D1: 6.4V 1.3W; D3
D7: ID; LED_0603
D8: ERROR; LED_0603
D9: COMM; LED_0603
D10, D11, D12, D13, D14, D15, D16, D17: 7seg_4digit_cc; 7seg_4digit_cc_modified
F1: 2.5A MT; Fuseholder5x20_horiz_open_universal_Type-III
P1, P1#2: VIN; m3_pillar
P3, P3#2: GND; m3_pillar
P4: CONN_02X03; Socket_Strip_Straight_2x03
P5: SWD; Socket_Strip_Straight_1x04
Q1, Q2, Q3, Q4, Q5, Q6, Q7, Q8: AO3415A; SOT-23_Handsoldering
Q14: Q_PNP_BEC; SOT-23_Handsoldering
Q15, Q16: Q_NPN_BEC; SOT-23_Handsoldering
R3: 47k; R_0603_HandSoldering
R4, R33, R34: 100k; R_0603_HandSoldering
R5: 10k; R_0603_HandSoldering
R35, R37: 100; R_0603_HandSoldering
R36: 140; R_0603_HandSoldering
R38, R39, R40, R41: R; R_0603_HandSoldering
R44: 1k; R_0603_HandSoldering
SW2: RESET; SW_SPST_FSMSM
U1: LD1117S33CTR; SOT-223
U2: SP3485CN; SOIC-8_3.9x4.9mm_Pitch1.27mm
U3: STM32F030F4Px; TSSOP-20_4.4x6.5mm_Pitch0.65mm
U5, U7: 74HC595_mine; SOIC-16_3.9x9.9mm_Pitch1.27mm
U8, U9: MBI5026; SSOP24-1.0-nosilk
U10: 74HCT125; SOIC-14_3.9x8.7mm_Pitch1.27mm
Y1: 25M; CRYSTAL-SMD-5X3
svg2mod: G***; label_fuse_04
svg2mod#2, svg2mod#8: G***; label_plus_04
svg2mod#3, svg2mod#4, svg2mod#9: G***; label_gnd_04
svg2mod#5: G***; label_comm_04
svg2mod#6: G***; label_error_04
svg2mod#7: G***; label_id_04
svg2mod#10: G***; label_data_04

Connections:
+3V3: C1.2, C5.2, C6.2, C9.2, C10.1, P5.4, R3.1, R5.2, U1.2, U1.4, U2.8, U3.5, U3.16, U5.10, U5.16
+5V: C2.2, C4.2, C7.2, C8.2, P4.2, P4.5, Q14.2, U1.3, U7.10, U7.16, U8.24, U9.24, U10.14
/AUX_STROBE: U3.18, U5.12, U7.12
/LED_COMM: R37.1, U5.2
/LED_ERROR: R36.1, U5.1
/LED_ID: R35.1, U5.3
/MOSI_C0: U3.13, U5.14, U10.9
/MOSI_C0_HV: U9.2, U10.8
/MOSI_C1_HV: U8.2, U9.22
/MOSI_C2: U5.9, U7.14
/RS485_A: P4.3, U2.6
/RS485_B: P4.4, U2.7
/RS485_DE: R4.1, U2.2, U2.3, U3.7
/RS485_RX: U2.1, U3.9
/RS485_TX: U2.4, U3.8
/RST: C11.1, R3.2, SW2.1, U3.4
/R_SET_0: Q15.3, R38.1, R40.1
/R_SET_1: Q16.3, R39.1, R41.1
/R_SET_CTRL0: R33.2, U5.6
/R_SET_CTRL1: R34.2, U5.7
/SCK: U3.11, U5.11, U7.11, U10.12
/SCK_HV: U8.3, U9.3, U10.11
/SEGC0: Q6.1, U7.15
/SEGC1: Q8.1, U7.1
/SEGC2: Q4.1, U7.2
/SEGC3: Q1.1, U7.3
/SEGC4: Q2.1, U7.4
/SEGC5: Q7.1, U7.5
/SEGC6: Q3.1, U7.6
/SEGC7: Q5.1, U7.7
/SEG_A_COM: D10.7, D11.7, D12.7, D13.7, D14.11, D15.11, D16.11, D17.11, Q8.2
/SEG_B_COM: D10.11, D11.11, D12.11, D13.11, D14.7, D15.7, D16.7, D17.7, Q3.2
/SEG_C_COM: D10.2, D11.2, D12.2, D13.2, D14.4, D15.4, D16.4, D17.4, Q1.2
/SEG_DP_COM: D10.3, D11.3, D12.3, D13.3, D14.3, D15.3, D16.3, D17.3, Q5.2
/SEG_D_COM: D10.4, D11.4, D12.4, D13.4, D14.2, D15.2, D16.2, D17.2, Q4.2
/SEG_E_COM: D10.5, D11.5, D12.5, D13.5, D14.1, D15.1, D16.1, D17.1, Q6.2
/SEG_F_COM: D10.10, D11.10, D12.10, D13.10, D14.10, D15.10, D16.10, D17.10, Q7.2
/SEG_G_COM: D10.1, D11.1, D12.1, D13.1, D14.5, D15.5, D16.5, D17.5, Q2.2
/STROBE: U3.17, U10.2
/STROBE_HV: U8.4, U9.4, U10.3
/SWCLK: P5.2, U3.20
/SWDIO: P5.1, U3.19
/VDD_PRE_FUSE: F1.1, P1.1, P1#2.1
/XT1: C12.2, U3.2, Y1.1
/XT2: C13.2, U3.3, Y1.3
/~OE: R5.1, U3.12, U10.5
/~OE_HV: R44.2, U10.6
/~OE_HV_CB: Q14.3, R44.1, U8.21, U9.21
GND: C1.1, C2.1, C3.2, C4.1, C5.1, C6.1, C7.1, C8.1, C9.1, C10.2, C11.2, C12.1, C13.1, C19.2, D1.2, D7.1, D8.1, D9.1, P3.1, P3#2.1, P4.1, P4.6, P5.3, Q15.2, Q16.2, R4.2, SW2.2, U1.1, U2.5, U3.1, U3.15, U5.8, U5.13, U7.8, U7.13, U8.1, U9.1, U10.1, U10.4, U10.7, U10.10, U10.13
unnamed: D7.2, R35.2
unnamed: D8.2, R36.2
unnamed: D9.2, R37.2
unnamed: D10.6, U8.8
unnamed: D10.8, U8.7
unnamed: D10.9, U8.6
unnamed: D10.12, U8.5
unnamed: D11.6, U8.12
unnamed: D11.8, U8.11
unnamed: D11.9, U8.10
unnamed: D11.12, U8.9
unnamed: D12.6, U8.13
unnamed: D12.8, U8.14
unnamed: D12.9, U8.15
unnamed: D12.12, U8.17
unnamed: D13.6, U8.20
unnamed: D13.8, U8.19
unnamed: D13.9, U8.18
unnamed: D13.12, U8.16
unnamed: D14.6, U9.5
unnamed: D14.8, U9.11
unnamed: D14.9, U9.8
unnamed: D14.12, U9.6
unnamed: D15.6, U9.9
unnamed: D15.8, U9.10
unnamed: D15.9, U9.12
unnamed: D15.12, U9.7
unnamed: D16.6, U9.13
unnamed: D16.8, U9.16
unnamed: D16.9, U9.15
unnamed: D16.12, U9.14
unnamed: D17.6, U9.17
unnamed: D17.8, U9.20
unnamed: D17.9, U9.19
unnamed: D17.12, U9.18
unnamed: Q15.1, R33.1
unnamed: Q16.1, R34.1
unnamed: R38.2, R39.2, U8.23
unnamed: R40.2, R41.2, U9.23
VDD: C3.1, C19.1, D1.1, F1.2, Q1.3, Q2.3, Q3.3, Q4.3, Q5.3, Q6.3, Q7.3, Q8.3

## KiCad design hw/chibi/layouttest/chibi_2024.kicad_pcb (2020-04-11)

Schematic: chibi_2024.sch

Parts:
C1, C2, C4, C5, C6, C7, C8, C9, C20: 100n; C_0603_HandSoldering
C3, C19: 1000u; C_Radial_D10_L20_P5
C10: 47u; c_elec_5x5.8
C11: 10n; C_0603_HandSoldering
C12, C13: 22p; C_0603_HandSoldering
D1: 6.4V 1.3W; D3
D2, D3, D4: D_Small; MiniMELF_Standard
D7: ID; LED_0603
D8: ERROR; LED_0603
D9: COMM; LED_0603
F1: 2.5A MT; Fuseholder5x20_horiz_open_inline_Type-I
JP1: rpos; solder_jumper_3mm
JP2: rneg; solder_jumper_3mm
JP3: lpos; solder_jumper_3mm
JP4: lneg; solder_jumper_3mm
P1, P2, P3, P6: SUP; m3_pillar
P4: CONN_02X03; Socket_Strip_Straight_2x03
P5: SWD; Socket_Strip_Straight_1x04
Q1, Q2, Q3, Q4, Q5, Q6, Q7, Q8: AO3415A; SOT-23_Handsoldering
Q14: Q_PNP_BEC; SOT-23_Handsoldering
Q15, Q16: Q_NPN_BEC; SOT-23_Handsoldering
R1, R3, R20, R25, R29: 47k; R_0603_HandSoldering
R4, R22, R32, R33, R34: 100k; R_0603_HandSoldering
R5, R19, R24: 10k; R_0603_HandSoldering
R21, R23: 470k; R_0603_HandSoldering
R35, R37: 100; R_0603_HandSoldering
R36: 140; R_0603_HandSoldering
R44: 1k; R_0603_HandSoldering
SW2: RESET; SW_SPST_FSMSM
U1: LD1117S33CTR; SOT-223
U2: SP3485CN; SOIC-8_3.9x4.9mm_Pitch1.27mm
U3: STM32F030F4Px; TSSOP-20_4.4x6.5mm_Pitch0.65mm
U5, U7: 74HC595_mine; SOIC-16_3.9x9.9mm_Pitch1.27mm
U6: LM393; SOIC-8_3.9x4.9mm_Pitch1.27mm
U10: 74HCT125; SOIC-14_3.9x8.7mm_Pitch1.27mm
Y1: 25M; CRYSTAL-SMD-5X3

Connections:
+3V3: C1.2, C5.2, C6.2, C9.2, C10.1, P5.4, R3.1, R5.2, U1.2 (VO), U2.8 (VCC), U3.5 (VDDA), U3.16 (VDD), U5.10 (~MR), U5.16 (VCC)
+5V: C2.2, C3.1, C4.2, C7.2, C8.2, C19.1, D1.1 (K), F1.1, P4.2, P4.5, Q1.3 (D), Q2.3 (D), Q3.3 (D), Q4.3 (D), Q5.3 (D), Q6.3 (D), Q7.3 (D), Q8.3 (D), Q14.2 (E), R20.1, R22.2, R25.2, U1.3 (VI), U6.8 (V+), U7.10 (~MR), U7.16 (VCC), U10.14 (VCC); also elsewhere on the board
/AUX_STROBE: U3.18 (I2C1_SDA/TIM17_BKIN/TIM1_CH3/USART1_RX/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), U5.12 (STCP), U7.12 (STCP)
/LED_COMM: R37.1, U5.2 (Q2)
/LED_ERROR: R36.1, U5.1 (Q1)
/LED_ID: R35.1, U5.3 (Q3)
/MOSI_C0: U3.13 (ADC_IN7/SPI1_MOSI/TIM14_CH1/TIM17_CH1/T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), U5.14 (DS), U10.9 (I2)
/MOSI_C0_HV: U10.8 (Q2); also elsewhere on the board
/MOSI_C2: U5.9 (Q7S), U7.14 (DS)
/RS485_A: P4.3, U2.6 (A)
/RS485_B: P4.4, U2.7 (B)
/RS485_DE: R4.1, U2.2 (~RE~), U2.3 (DE), U3.7 (ADC_IN1/USART1_DE/USART1_RTS/PA1)
/RS485_RX: U2.1 (RO), U3.9 (ADC_IN3/USART1_RX/PA3)
/RS485_TX: U2.4 (DI), U3.8 (ADC_IN2/USART1_TX/PA2)
/RST: C11.1, D2.2 (A), R3.2, SW2.1, U3.4 (NRST)
/R_SET_CTRL0: R33.2, U5.6 (Q6)
/R_SET_CTRL1: R34.2, U5.7 (Q7)
/SCK: U3.11 (ADC_IN5/SPI1_SCK/PA5), U5.11 (SHCP), U7.11 (SHCP), U10.12 (I3)
/SCK_HV: U10.11 (Q3); also elsewhere on the board
/SEG_A_COM: Q7.2 (S); also elsewhere on the board
/SEG_A_CTRL: Q7.1 (G), U7.7 (Q7)
/SEG_B_COM: Q3.2 (S); also elsewhere on the board
/SEG_B_CTRL: Q3.1 (G), U7.6 (Q6)
/SEG_C_COM: Q1.2 (S); also elsewhere on the board
/SEG_C_CTRL: Q1.1 (G), U7.1 (Q1)
/SEG_DP_COM: Q4.2 (S); also elsewhere on the board
/SEG_DP_CTRL: Q4.1 (G), R32.2, U7.2 (Q2)
/SEG_D_COM: Q6.2 (S); also elsewhere on the board
/SEG_D_CTRL: Q6.1 (G), U7.3 (Q3)
/SEG_E_COM: Q8.2 (S); also elsewhere on the board
/SEG_E_CTRL: Q8.1 (G), U7.5 (Q5)
/SEG_F_COM: Q5.2 (S); also elsewhere on the board
/SEG_F_CTRL: Q5.1 (G), U7.4 (Q4)
/SEG_G_COM: Q2.2 (S); also elsewhere on the board
/SEG_G_CTLR: Q2.1 (G), U7.15 (Q0)
/STROBE: U3.17 (I2C1_SCL/TIM1_CH2/USART1_TX/PA9), U10.2 (I0)
/STROBE_HV: U10.3 (Q0); also elsewhere on the board
/SWCLK: P5.2, U3.20 (SYS_SWCLK/USART1_TX/PA14)
/SWDIO: P5.1, U3.19 (IR_OUT/SYS_SWDIO/PA13)
/WD_COMP1: C20.1, R32.1, U6.6 (_)
/WD_REF1: R23.1, R25.1, R29.2, U6.3 (+)
/WD_REF2: R21.1, R22.1, R24.2, U6.5 (+)
/XT1: C12.2, U3.2 (PF0/RCC_OSC_IN), Y1.1
/XT2: C13.2, U3.3 (PF1/RCC_OSC_OUT), Y1.3
/in_left: JP1.1, JP2.1, P1.1, P2.1
/in_right: JP3.1, JP4.1, P3.1, P6.1
/mux_mod_left/R_SET_0: Q15.3 (C); also elsewhere on the board
/mux_mod_left/R_SET_1: Q16.3 (C); also elsewhere on the board
/~OE: R5.1, U3.12 (ADC_IN6/SPI1_MISO/TIM16_CH1/TIM1_BKIN/T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), U10.5 (I1)
/~OE_HV: R44.2, U10.6 (Q1)
/~OE_HV_CB: Q14.3 (C), R44.1; also elsewhere on the board
/~WD_RST: D2.1 (K), D3.2 (A), D4.2 (A), R19.2, R20.2
/~WD_RST1: D3.1 (K), R23.2, U6.1
/~WD_RST2: D4.1 (K), R21.2, U6.7
GND: C1.1, C2.1, C3.2, C4.1, C5.1, C6.1, C7.1, C8.1, C9.1, C10.2, C11.2, C12.1, C13.1, C19.2, C20.2, D1.2 (A), D7.1, D8.1, D9.1, JP2.2, JP4.2, P4.1, P4.6, P5.3, Q15.2 (E), Q16.2 (E), R1.1, R4.2, R24.1, R29.1, SW2.2, U1.1 (GND), U2.5 (GND), U3.1 (BOOT0), U3.15 (VSS), U5.8 (GND), U5.13 (~OE), U6.4 (V-), U7.8 (GND), U7.13 (~OE), U10.1 (~OE0), U10.4 (~OE1), U10.7 (GND), U10.10 (~OE2), U10.13 (~OE3); also elsewhere on the board
unnamed: F1.2, JP1.2, JP3.2
unnamed: Q14.1 (B), R19.1
unnamed: Q15.1 (B), R33.1
unnamed: Q16.1 (B), R34.1
unnamed: R1.2, U6.2 (_)

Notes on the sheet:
optional
Chibi 2x4x(4x7)seg controller
Each mux module contains 4 four-digit 7-segment displays
Vin trimmed to lowest sensible value to reduce power dissipation. Vin ~~= Vdrop + Vfw + Vfet + Vshunt + Vwiring = 1.0 + 1.85 + 0.25 + 0.25 + 0.25 = 3.6V
Status leds

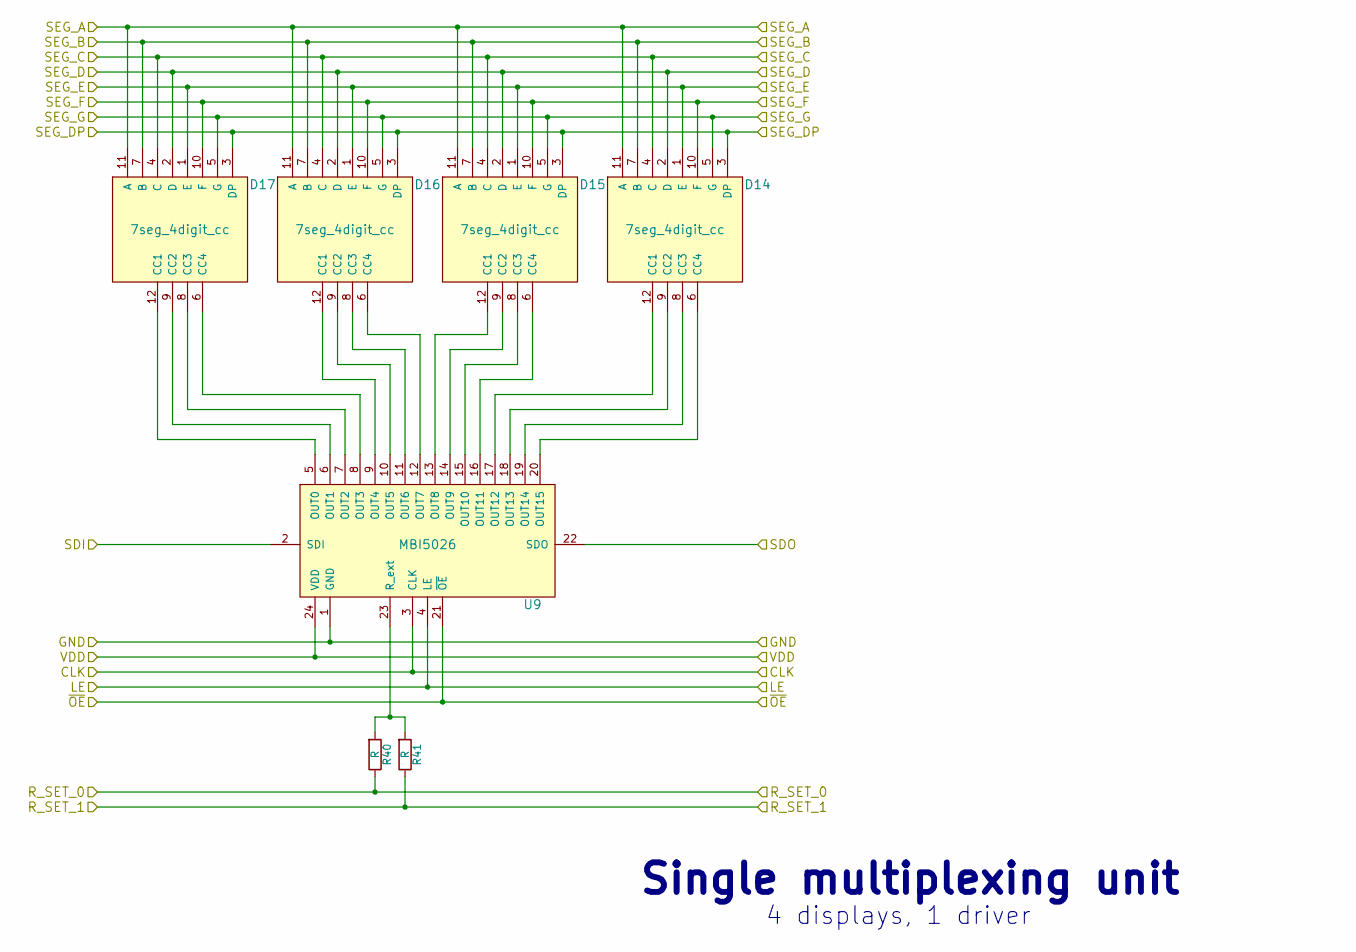
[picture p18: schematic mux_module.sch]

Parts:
D14, D15, D16, D17: 7seg_4digit_cc; 7seg_4digit_cc_modified
R38, R41: R; R_0603_HandSoldering
U9: MBI5026; SSOP24-1.0-nosilk

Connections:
+5V: U9.24 (VDD); also elsewhere on the board
/MOSI_C0_HV: U9.2 (SDI); also elsewhere on the board
/MOSI_C1_HV: U9.22 (SDO); also elsewhere on the board
/SCK_HV: U9.3 (CLK); also elsewhere on the board
/SEG_A_COM: D14.11 (A), D15.11 (A), D16.11 (A), D17.11 (A); also elsewhere on the board
/SEG_B_COM: D14.7 (B), D15.7 (B), D16.7 (B), D17.7 (B); also elsewhere on the board
/SEG_C_COM: D14.4 (C), D15.4 (C), D16.4 (C), D17.4 (C); also elsewhere on the board
/SEG_DP_COM: D14.3 (DP), D15.3 (DP), D16.3 (DP), D17.3 (DP); also elsewhere on the board
/SEG_D_COM: D14.2 (D), D15.2 (D), D16.2 (D), D17.2 (D); also elsewhere on the board
/SEG_E_COM: D14.1 (E), D15.1 (E), D16.1 (E), D17.1 (E); also elsewhere on the board
/SEG_F_COM: D14.10 (F), D15.10 (F), D16.10 (F), D17.10 (F); also elsewhere on the board
/SEG_G_COM: D14.5 (G), D15.5 (G), D16.5 (G), D17.5 (G); also elsewhere on the board
/STROBE_HV: U9.4 (LE); also elsewhere on the board
/mux_mod_left/R_SET_0: R38.1; also elsewhere on the board
/mux_mod_left/R_SET_1: R41.1; also elsewhere on the board
/~OE_HV_CB: U9.21 (~OE); also elsewhere on the board
GND: U9.1 (GND); also elsewhere on the board
unnamed: D14.6 (CC4), U9.20 (OUT15)
unnamed: D14.8 (CC3), U9.19 (OUT14)
unnamed: D14.9 (CC2), U9.18 (OUT13)
unnamed: D14.12 (CC1), U9.17 (OUT12)
unnamed: D15.6 (CC4), U9.16 (OUT11)
unnamed: D15.8 (CC3), U9.15 (OUT10)
unnamed: D15.9 (CC2), U9.14 (OUT9)
unnamed: D15.12 (CC1), U9.13 (OUT8)
unnamed: D16.6 (CC4), U9.12 (OUT7)
unnamed: D16.8 (CC3), U9.11 (OUT6)
unnamed: D16.9 (CC2), U9.10 (OUT5)
unnamed: D16.12 (CC1), U9.9 (OUT4)
unnamed: D17.6 (CC4), U9.8 (OUT3)
unnamed: D17.8 (CC3), U9.7 (OUT2)
unnamed: D17.9 (CC2), U9.6 (OUT1)
unnamed: D17.12 (CC1), U9.5 (OUT0)

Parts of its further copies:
D10, D11, D12, D13: 7seg_4digit_cc; 7seg_4digit_cc_modified
R39, R40: R; R_0603_HandSoldering
U8: MBI5026; SSOP24-1.0-nosilk

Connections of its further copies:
+5V: U8.24 (VDD); also elsewhere on the board
/MOSI_C1_HV: U8.2 (SDI); also elsewhere on the board
/SCK_HV: U8.3 (CLK); also elsewhere on the board
/SEG_A_COM: D10.11 (A), D11.11 (A), D12.11 (A), D13.11 (A); also elsewhere on the board
/SEG_B_COM: D10.7 (B), D11.7 (B), D12.7 (B), D13.7 (B); also elsewhere on the board
/SEG_C_COM: D10.4 (C), D11.4 (C), D12.4 (C), D13.4 (C); also elsewhere on the board
/SEG_DP_COM: D10.3 (DP), D11.3 (DP), D12.3 (DP), D13.3 (DP); also elsewhere on the board
/SEG_D_COM: D10.2 (D), D11.2 (D), D12.2 (D), D13.2 (D); also elsewhere on the board
/SEG_E_COM: D10.1 (E), D11.1 (E), D12.1 (E), D13.1 (E); also elsewhere on the board
/SEG_F_COM: D10.10 (F), D11.10 (F), D12.10 (F), D13.10 (F); also elsewhere on the board
/SEG_G_COM: D10.5 (G), D11.5 (G), D12.5 (G), D13.5 (G); also elsewhere on the board
/STROBE_HV: U8.4 (LE); also elsewhere on the board
/mux_mod_left/R_SET_0: R40.1; also elsewhere on the board
/mux_mod_left/R_SET_1: R39.1; also elsewhere on the board
/mux_mod_right/SDO: U8.22 (SDO)
/~OE_HV_CB: U8.21 (~OE); also elsewhere on the board
GND: U8.1 (GND); also elsewhere on the board
unnamed: D10.6 (CC4), U8.20 (OUT15)
unnamed: D10.8 (CC3), U8.19 (OUT14)
unnamed: D10.9 (CC2), U8.18 (OUT13)
unnamed: D10.12 (CC1), U8.17 (OUT12)
unnamed: D11.6 (CC4), U8.16 (OUT11)
unnamed: D11.8 (CC3), U8.15 (OUT10)
unnamed: D11.9 (CC2), U8.14 (OUT9)
unnamed: D11.12 (CC1), U8.13 (OUT8)
unnamed: D12.6 (CC4), U8.12 (OUT7)
unnamed: D12.8 (CC3), U8.11 (OUT6)
unnamed: D12.9 (CC2), U8.10 (OUT5)
unnamed: D12.12 (CC1), U8.9 (OUT4)
unnamed: D13.6 (CC4), U8.8 (OUT3)
unnamed: D13.8 (CC3), U8.7 (OUT2)
unnamed: D13.9 (CC2), U8.6 (OUT1)
unnamed: D13.12 (CC1), U8.5 (OUT0)

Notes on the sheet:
Single multiplexing unit
4 displays, 1 driver

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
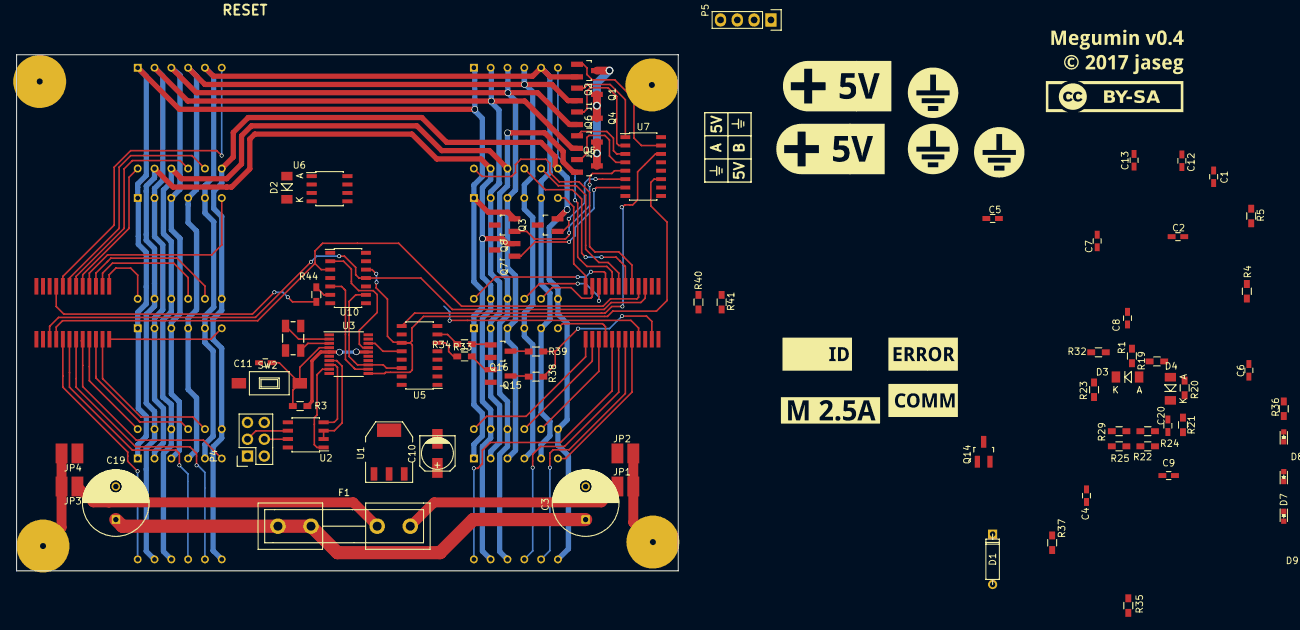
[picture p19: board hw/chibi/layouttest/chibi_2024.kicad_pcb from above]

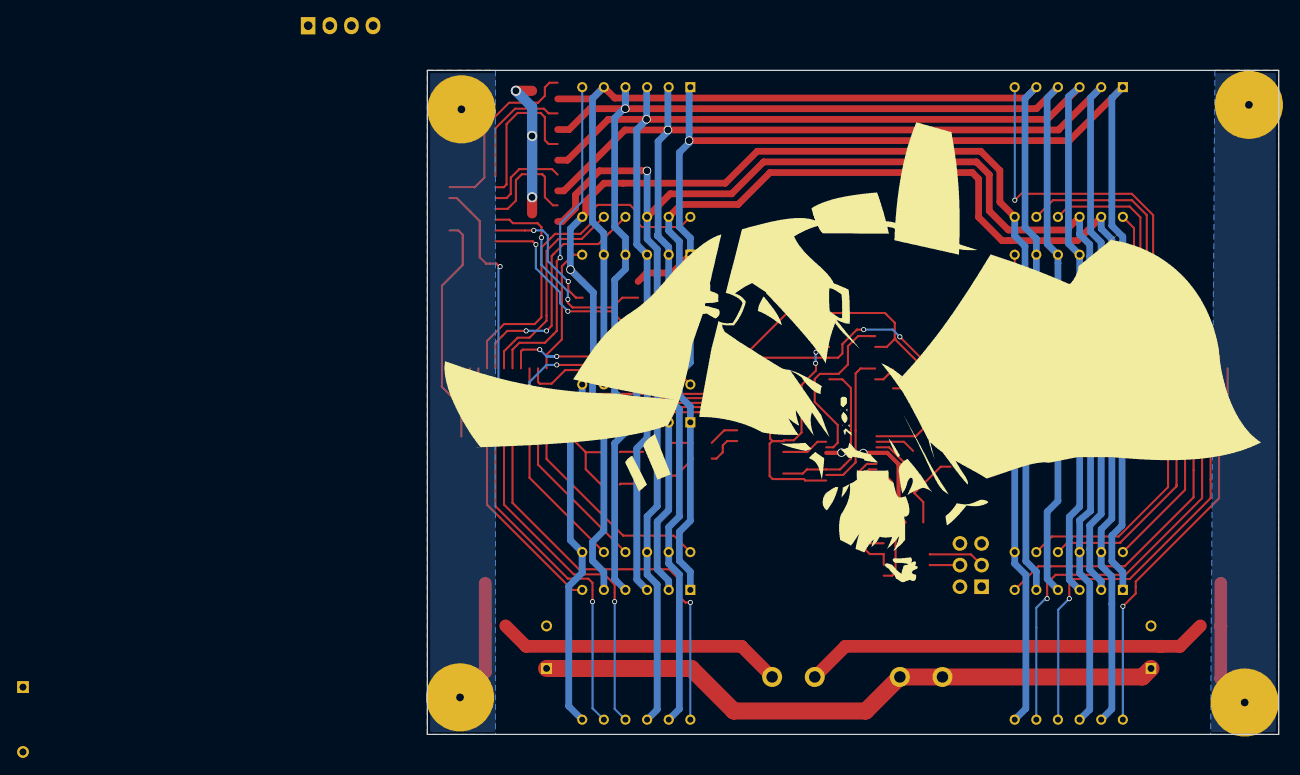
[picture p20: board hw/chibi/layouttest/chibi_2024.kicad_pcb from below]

Board: 2 copper layers, 100.0 x 78.0 mm, 97 parts (9 on the bottom side), 95 nets.

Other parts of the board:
svg2mod: G***; megumin
svg2mod#2: G***; label_fuse_04
svg2mod#3, svg2mod#9: G***; label_plus_04
svg2mod#4, svg2mod#5, svg2mod#10: G***; label_gnd_04
svg2mod#6: G***; label_comm_04
svg2mod#7: G***; label_error_04
svg2mod#8: G***; label_id_04
svg2mod#11: G***; label_data_04

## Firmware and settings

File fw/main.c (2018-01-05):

/* Megumin LED display firmware
 * Copyright (C) 2018 Sebastian Götte <code@jaseg.net>
 * 
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
 * You should have received a copy of the GNU General Public License
 * along with this program.  If not, see <http://www.gnu.org/licenses/>.
 */

#include "global.h"

#include "display.h"
#include "serial.h"
#include "led.h"
#include "adc.h"

volatile unsigned int sys_time = 0;
volatile unsigned int sys_time_seconds = 0;

int main(void) {
    RCC->CR |= RCC_CR_HSEON;
    while (!(RCC->CR&RCC_CR_HSERDY));
    RCC->CFGR &= ~RCC_CFGR_PLLMUL_Msk & ~RCC_CFGR_SW_Msk & ~RCC_CFGR_PPRE_Msk & ~RCC_CFGR_HPRE_Msk;
    RCC->CFGR |= (2<<RCC_CFGR_PLLMUL_Pos) | RCC_CFGR_PLLSRC_HSE_PREDIV; /* PLL x4 -> 50.0MHz */
    RCC->CFGR2 &= ~RCC_CFGR2_PREDIV_Msk;
    RCC->CFGR2 |= RCC_CFGR2_PREDIV_DIV2; /* prediv :2 -> 12.5MHz */
    RCC->CR |= RCC_CR_PLLON;
    while (!(RCC->CR&RCC_CR_PLLRDY));
    RCC->CFGR |= (2<<RCC_CFGR_SW_Pos);
    SystemCoreClockUpdate();

    /* Turn on lots of neat things */
    RCC->AHBENR  |= RCC_AHBENR_GPIOAEN | RCC_AHBENR_DMAEN | RCC_AHBENR_CRCEN | RCC_AHBENR_FLITFEN;
    RCC->APB2ENR |= RCC_APB2ENR_SPI1EN | RCC_APB2ENR_USART1EN | RCC_APB2ENR_SYSCFGEN | RCC_APB2ENR_ADCEN | RCC_APB2ENR_DBGMCUEN | RCC_APB2ENR_TIM1EN;
    RCC->APB1ENR |= RCC_APB1ENR_TIM3EN;

    GPIOA->MODER |=
          (1<<GPIO_MODER_MODER0_Pos)  /* PA0  - Debug */
        | (2<<GPIO_MODER_MODER1_Pos)  /* PA1  - RS485 DE */
        | (2<<GPIO_MODER_MODER2_Pos)  /* PA2  - RS485 TX */
        | (2<<GPIO_MODER_MODER3_Pos)  /* PA3  - RS485 RX */
        | (1<<GPIO_MODER_MODER4_Pos)  /* PA4  - Debug */
        | (2<<GPIO_MODER_MODER5_Pos)  /* PA5  - SCLK */
        | (2<<GPIO_MODER_MODER6_Pos)  /* PA6  - LED !OE */
        | (2<<GPIO_MODER_MODER7_Pos)  /* PA7  - MOSI */
        | (2<<GPIO_MODER_MODER9_Pos)  /* PA9  - LED strobe */
        | (1<<GPIO_MODER_MODER10_Pos);/* PA10 - Auxiliary strobe */

    /* Set shift register IO GPIO output speed */
    GPIOA->OSPEEDR |=
          (2<<GPIO_OSPEEDR_OSPEEDR0_Pos)   /* Debug */
        | (2<<GPIO_OSPEEDR_OSPEEDR1_Pos)   /* RS485 DE */
        | (2<<GPIO_OSPEEDR_OSPEEDR2_Pos)   /* TX */
        | (2<<GPIO_OSPEEDR_OSPEEDR3_Pos)   /* RX */
        | (2<<GPIO_OSPEEDR_OSPEEDR4_Pos)   /* Debug */
        | (2<<GPIO_OSPEEDR_OSPEEDR5_Pos)   /* SCLK */
        | (2<<GPIO_OSPEEDR_OSPEEDR6_Pos)   /* LED !OE   */
        | (2<<GPIO_OSPEEDR_OSPEEDR7_Pos)   /* MOSI */
        | (2<<GPIO_OSPEEDR_OSPEEDR9_Pos)   /* LED strobe */
        | (2<<GPIO_OSPEEDR_OSPEEDR10_Pos); /* Auxiliary strobe */

    GPIOA->AFR[0] |=
          (1<<GPIO_AFRL_AFRL1_Pos)   /* USART1_RTS (DE) */
        | (1<<GPIO_AFRL_AFRL2_Pos)   /* USART1_TX */
        | (1<<GPIO_AFRL_AFRL3_Pos)   /* USART1_RX */
        | (0<<GPIO_AFRL_AFRL5_Pos)   /* SPI1_SCK */
        | (1<<GPIO_AFRL_AFRL6_Pos)   /* TIM3_CH1 */
        | (0<<GPIO_AFRL_AFRL7_Pos);  /* SPI1_MOSI */
    GPIOA->AFR[1] |=
          (2<<GPIO_AFRH_AFRH1_Pos);  /* TIM1_CH2 */

    GPIOA->PUPDR |=
          (2<<GPIO_PUPDR_PUPDR1_Pos)  /* RS485 DE: Pulldown */
        | (1<<GPIO_PUPDR_PUPDR2_Pos)  /* TX */
        | (1<<GPIO_PUPDR_PUPDR3_Pos); /* RX */

    display_init();
    SysTick_Config(SystemCoreClock/1000); /* 1ms interval */
    serial_init();
    adc_init();

    while (42) {
        led_task();

        /* Process pending buffer transfer */
        if (fb_op == FB_FORMAT) {
            transpose_data(rx_buf.byte_data, write_fb);
            fb_op = FB_UPDATE;
        }
    }
}

void NMI_Handler(void) {
}

void HardFault_Handler(void) __attribute__((naked));
void HardFault_Handler() {
    asm volatile ("bkpt");
}

void SVC_Handler(void) {
}


void PendSV_Handler(void) {
}

void SysTick_Handler(void) {
    static int n = 0;
    sys_time++;
    if (n++ == 1000) {
        n = 0;
        sys_time_seconds++;
    }
}

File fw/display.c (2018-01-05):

/* Megumin LED display firmware
 * Copyright (C) 2018 Sebastian Götte <code@jaseg.net>
 * 
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
 * You should have received a copy of the GNU General Public License
 * along with this program.  If not, see <http://www.gnu.org/licenses/>.
 */

#include "led.h"
#include "display.h"

volatile int frame_duration_us = 0;
volatile int nbits = MAX_BITS;

/* Modulation data */
volatile enum FB_OPERATION fb_op;
static volatile struct framebuf fb[2] = {0};
volatile struct framebuf *read_fb=fb+0, *write_fb=fb+1;

/* Auxiliary shift register values */
#define LED_COMM     0x0001
#define LED_ERROR    0x0002
#define LED_ID       0x0004
#define SR_ILED_HIGH 0x0080
#define SR_ILED_LOW  0x0040

/* This is a lookup table mapping segments to present a standard segment order on the UART interface. This is converted
 * into an internal representation once on startup in main(). The data type must be at least uint16. */
static uint32_t segment_map[8] = {5, 7, 6, 4, 1, 3, 0, 2};

static unsigned int active_bit = 0;
static int active_segment = 0;

/* Bit timing base value. This is the lowes bit interval used in TIM1/TIM3 timer counts. */
#define PERIOD_BASE 4

/* This value is a constant offset added to every bit period to allow for the timer IRQ handler to execute. This is set
 * empirically using a debugger and a logic analyzer.
 *
 * This value is in TIM1/TIM3 timer counts. */
#define TIMER_CYCLES_FOR_SPI_TRANSMISSIONS 9

/* This value sets the point when the LED strobe is asserted after the begin of the current bit cycle and IRQ
 * processing. This must be less than TIMER_CYCLES_FOR_SPI_TRANSMISSIONS but must be large enough to allow for the SPI
 * transmission to reliably finish.
 *
 * This value is in TIM1/TIM3 timer counts. */
#define TIMER_CYCLES_BEFORE_LED_STROBE 8

/* This value sets how long the TIM1 CC IRQ used for AUX register setting etc. is triggered before the end of the
 * longest cycle. This value should not be larger than PERIOD_BASE<<MIN_BITS to make sure the TIM1 CC IRQ does only
 * trigger in the longest cycle no matter what nbits is set to.
 *
 * This value is in TIM1/TIM3 timer counts. */
#define AUX_SPI_PRETRIGGER 64 /* trigger with about 24us margin to the end of cycle/next TIM3 IRQ */

/* This value sets how long a batch of ADC conversions used for temperature measurement is started before the end of the
 * longest cycle. Here too the above caveats apply.
 *
 * This value is in TIM1/TIM3 timer counts. */
#define ADC_PRETRIGGER 150 /* trigger with about 12us margin to TIM1 CC IRQ */

/* Defines for brevity */
#define A TIMER_CYCLES_FOR_SPI_TRANSMISSIONS
#define B PERIOD_BASE

/* This is a constant offset containing some empirically determined correction values */
#define C (0)

/* This lookup table maps bit positions to timer period values. This is a lookup table to allow for the compensation for
 * non-linear effects of ringing at lower bit durations.
 */
static uint16_t timer_period_lookup[MAX_BITS+1] = {
    /* LSB here */
    A - C + (B<< 0),
    A - C + (B<< 1),
    A - C + (B<< 2),
    A - C + (B<< 3),
    A - C + (B<< 4),
    A - C + (B<< 5),
    A - C + (B<< 6),
    A - C + (B<< 7),
    A - C + (B<< 8),
    A - C + (B<< 9),
    A - C + (B<< 0),
    /* MSB here */
};

/* Don't pollute the global namespace */
#undef A
#undef B
#undef C

void display_cfg_timers(void);
void display_cfg_spi(void);

void display_init() {
    display_cfg_spi();

    /* Pre-compute aux register values for timer ISR */
    for (int i=0; i<NSEGMENTS; i++) {
        segment_map[i] = 0xff00 ^ (0x100<<segment_map[i]);
    }

    /* Clear frame buffer */
    read_fb->brightness = 1;
    for (int i=0; i<sizeof(read_fb->data)/sizeof(uint32_t); i++) {
        read_fb->data[i] = 0xffffffff; /* FIXME this is a debug value. Should be 0x00000000; */
    }

    display_cfg_timers();
}

void display_cfg_spi() {
    /* Configure SPI controller */
    SPI1->I2SCFGR = 0;
    SPI1->CR2 &= ~SPI_CR2_DS_Msk;
    SPI1->CR2 &= ~SPI_CR2_DS_Msk;
    SPI1->CR2 |= LL_SPI_DATAWIDTH_16BIT;

    /* Baud rate PCLK/4 -> 12.5MHz */
    SPI1->CR1 =
          SPI_CR1_BIDIMODE
        | SPI_CR1_BIDIOE
        | SPI_CR1_SSM
        | SPI_CR1_SSI
        | SPI_CR1_SPE
        | (1<<SPI_CR1_BR_Pos)
        | SPI_CR1_MSTR
        | SPI_CR1_CPOL
        | SPI_CR1_CPHA;
    /* FIXME maybe try w/o BIDI */
}

void display_cfg_timers() {
    /* Ok, so this part is unfortunately a bit involved.
     *
     * Because the GPIO alternate function assignments worked out that way, the LED driving logic uses timers 1 and 3.
     * Timer 1 is synchronized to timer 3. When timer 3 overflows, timer 1 is reset. Both use the same prescaler so both
     * are synchronous possibly modulo some propagation delay in the synchronization hardware.
     *
     * Timer 3:
     *  * The IRQ handler is set to trigger on overflow and
     *    * triggers the SPI transmissions to the LED drivers and
     *    * updates the timing logic with the delays for the next cycle
     *  * Compare unit 1 generates the !OE signal for the led drivers
     * Timer 1:
     *  * Compare unit 1 triggers the interrupt handler only in the longest bit cycle. The IRQ handler
     *    * transmits the data to the auxiliary shift registers and
     *    * swaps the frame buffers if pending
     *  * Compare unit 2 generates the led drivers' STROBE signal
     * 
     * The AUX_STROBE signal for the two auxiliary shift registers that deal with segment selection, current setting and
     * status leds is generated in software in both ISRs. TIM3's ISR indiscriminately resets this strobe every bit
     * cycle, and TIM1's ISR sets it every NBITSth bit cycle.
     *
     * The reason both timers' IRQ handlers are used is that this way no big if/else statement is necessary to
     * distinguish between both cases. Timer 1's IRQ handler is set via CC2 to trigger a few cycles earlier than the end
     * of the longest bit cycle. This means that if both timers perform bit cycles of length 1, 2, 4, 8, 16 and 32
     * TIM1_CC2 will be set to trigger at count e.g. 28. This means it is only triggered once in the last timer cycle.
     */

    TIM3->CR2   = (2<<TIM_CR2_MMS_Pos); /* master mode: update */
    TIM3->CCMR1 = (6<<TIM_CCMR1_OC1M_Pos) | TIM_CCMR1_OC1PE; /* PWM Mode 1, enable CCR preload */
    TIM3->CCER  = TIM_CCER_CC1E;
    TIM3->CCR1  = TIMER_CYCLES_FOR_SPI_TRANSMISSIONS;
    TIM3->DIER  = TIM_DIER_UIE;
    TIM3->PSC   = SystemCoreClock/5000000 * 2 - 1; /* 0.20us/tick */
    TIM3->ARR   = 0xffff;
    TIM3->EGR  |= TIM_EGR_UG;
    TIM3->CR1   = TIM_CR1_ARPE;
    TIM3->CR1  |= TIM_CR1_CEN;

    /* Slave TIM1 to TIM3. */
    TIM1->PSC   = TIM3->PSC;
    TIM1->SMCR  = (2<<TIM_SMCR_TS_Pos) | (4<<TIM_SMCR_SMS_Pos); /* Internal Trigger 2 (ITR2) -> TIM3; slave mode: reset */
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

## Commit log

2017-04-28 Added protection stuff
    [chibi_2024.sch, mux_module.sch]
2017-04-29 Pre safety fixup
    [chibi_2024.kicad_pcb, chibi_2024.sch, mux_module.sch]
2017-05-02 Layout mostly done
    [chibi_2024.kicad_pcb, chibi_2024.sch]
2017-05-04 Design mostly done
    [chibi_2024-B.Cu.gbr, chibi_2024-B.Mask.gbr, chibi_2024-B.Paste.gbr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]
2017-05-17 Release v0.2
    [chibi_2024-B.Cu.gbr, chibi_2024-B.Mask.gbr, chibi_2024-B.Paste.gbr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]
2017-06-12 Add resistor calculation script
2017-07-15 Schematic fixed up so far
    [bom-chibi.ods, chibi_2024.kicad_pcb, chibi_2024.sch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]
2017-07-20 Second board revision
    [chibi_2024-B.Cu.gbr, chibi_2024-B.Mask.gbr, chibi_2024-B.Paste.gbr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]
2017-07-20 Final silk art positioning
    [chibi_2024-B.Cu.gbr, chibi_2024-B.Mask.gbr, chibi_2024-B.Paste.gbr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]
2017-07-21 Second production run, v0.3
    [chibi_2024-B.Cu.gbr, chibi_2024-B.Mask.gbr, chibi_2024-B.Paste.gbr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]
2017-08-13 Board rev 0.3 working
2017-08-15 Working on uart code
2017-08-23 Interrupt-driven SPI1 fundamentally working
2017-09-01 DMA channel assignments redone, basic protocol stuff working
2017-09-01 UART magic seems to be working now
2017-09-02 Temperature/VCC ADC working
2017-09-06 Fixes for second prototype (v0.3)
    [chibi_2024-B.Cu.gbr, chibi_2024-B.Mask.gbr, chibi_2024-B.Paste.gbr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]
2017-09-06 Fix up version label and one ground trace
    [chibi_2024-B.Cu.gbr, chibi_2024-B.Mask.gbr, chibi_2024-B.Paste.gbr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]
2017-09-06 Fix up RS485/digital power label
    [chibi_2024-B.Cu.gbr, chibi_2024-B.Mask.gbr, chibi_2024-B.Paste.gbr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]
2017-09-18 hw v0.4
    [chibi_2024-B.Cu.gbr, chibi_2024-B.Mask.gbr, chibi_2024-B.Paste.gbr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]
2017-12-08 Basic UART working, but too slow
    [main.c]
2017-12-09 Cycle timing is fixed again
    [main.c]
2017-12-09 UART and LEDs playing nicely
2017-12-10 Add lots of doc and fix segment driving
    [main.c, test.py]
2017-12-10 Rough ADC triggering works now
2017-12-10 ADC properly triggering now
2017-12-10 ADC temperature measurement works now
2017-12-10 Make comm and error LEDs useful
    [main.c, test.py]
2017-12-10 Prettify and document AUX LED handling
2017-12-10 Make status request work, fix uc-side cobs encoding bug
    [bom-chibi.ods]
2018-01-05 Add some documentation
    [bom-chibi.ods, chibi_2024.kicad_pcb]
2020-04-11 Add local changes
    [chibi_2024.kicad_pcb, chibi_2024.sch, layouttest.kicad_pcb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]

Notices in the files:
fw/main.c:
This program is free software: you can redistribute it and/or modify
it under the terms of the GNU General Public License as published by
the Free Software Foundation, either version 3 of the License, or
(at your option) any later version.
